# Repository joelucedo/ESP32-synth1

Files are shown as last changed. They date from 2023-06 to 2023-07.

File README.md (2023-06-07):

## ESP32 SYNTH
***ESP32 Wrover E/IE based synthesizer***

ESP32 synth

## STATUS
Work in progress.
</br>
## SPECS
Audio in/out and headphone,  MIDI in/out/thru, 16 pot + 1 volume pot, USB-C, reset switch

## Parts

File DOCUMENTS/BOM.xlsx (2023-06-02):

ESP32 SYNTH 1 - BOM
Ref | Description | Package/Mounting | Value | Quantity | Manufacturer | Manufacturer PN | Supplier | Supplier PN | Cost/Unit | Stock | Basic/Extended | Notes
RESISTORS
 | SMD Thick Film Resistors 125mW ±1% | 0805 | 33R |  | UNI-ROYAL | 0805W8F330JT5E | JLCPCB | C17634 |  |  | Basic
 | SMD Thick Film Resistors 125mW ±1% | 0805 | 100R |  | UNI-ROYAL | 0805W8F1000T5E | JLCPCB | C17408 |  |  | Basic
 | SMD Thick Film Resistors 100mW ±1% | 0603 | 220R |  | UNI-ROYAL | 0603WAF2200T5E | JLCPCB | C22962 |  |  | Basic
 | SMD Thick Film Resistors 100mW ±1% | 0603 | 1k |  | UNI-ROYAL | 0603WAF1001T5E | JLCPCB | C21190 |  |  | Basic
 | SMD Thick Film Resistors 100mW ±5% | 0603 | 1,5k |  | UNI-ROYAL | CQ03WAJ0152T5E | JLCPCB | C2759693 |  | 3458 | Extended
 | SMD Thick Film Resistors 100mW ±1% | 0603 | 2.2k |  | UNI-ROYAL | 0603WAF2201T5E | JLCPCB | C4190 |  |  | Basic
 | SMD Thick Film Resistors 100mW ±1% | 0603 | 5,1k |  | UNI-ROYAL | 0603WAF5101T5E | JLCPCB | C23186
 | SMD Thick Film Resistors 100mW ±1% | 0603 | 10k |  | UNI-ROYAL | 0603WAF1002T5E | JLCPCB | C25804 |  |  | Basic
 | SMD Thick Film Resistors 100mW ±1% | 0603 | 22k |  | UNI-ROYAL | 0603WAF2202T5E | JLCPCB | C31850 |  |  | Basic
 | SMD Thick Film Resistors 100mW ±1% | 0603 | 47k |  | UNI-ROYAL | 0603WAF4702T5E | JLCPCB | C25819 |  |  | Basic
 | SMD Thick Film Resistors 100mW ±1% | 0603 | 100k |  | UNI-ROYAL | 0603WAF1003T5E | JLCPCB | C25803
CAPACITORS
 | SMD MLCC 50V X7R ±10% | 0603 | 100nF |  | YAGEO | CC0603KRX7R9BB104 | JLCPCB | C14663 |  |  | Basic
 | SMD MLCC 50V X5R ±10% | 0603 | 1uF |  | Samsung Electro-Mechanics | CL10A105KB8NNNC | JLCPCB | C15849 |  |  | Basic
 | SMD MLCC 16V X5R ±10% | 0603 | 4.7uF |  | Samsung Electro-Mechanics | CL10A475KO8NNNC | JLCPCB | C19666 |  |  | Basic
 | SMD MLCC 25V X5R ±20% | 0603 | 10uF |  | Samsung Electro-Mechanics | CL10A106MA8NRNC | JLCPCB | C96446 |  |  | Basic
 | SMD MLCC 6.3V X5R ±20% | 0603 | 22uF |  | Samsung Electro-Mechanics | CL10A226MQ8NRNC | JLCPCB | C59461 |  |  | Basic
 | SMD Aluminum Electrolytic Capacitors 10V ±20% | SMD,D6.3xL5.4mm | 220uF |  | Honor Elec | RVT1A221M0605 | JLCPCB | C3345 |  | 52121 | Extended
INDUCTORS
 | SMD Inductor 1.8A ±20% 80mΩ | SMD 3.5x3x2.1mm | 2.2uH |  | YJYCOIN | CD32YP0302-2R2M | JLCPCB | C492258 |  | 222 | Extended
FERRITE BEAD
 | Ferrite Bead - 800mA - 80mΩ - ±25% | 0603 | 120R@100MHz |  | MURATA | BLM18AG121SN1D | JLCPCB | C76892 |  | 66550 | Extended
 | Ferrite bead - 1.3A - 150mΩ - ±25% | 0603 | 600R@100MHz |  | SUNLORD | UPZ1608U601-1R3TF | JLCPCB | C97000 |  | 91257 | Extended
INTEGRATED CIRCUITS
 | ESP32 Wrover E ou IE | SMD |  |  | ESPRESSIF
 | USB UART converter | QFN-28-EP(5x5) |  |  | SILICON LABS | CP2102N-A02-GQFN28R | JLCPCB | C964632 | $2.0723 | 1907 | Extended
 | Audio codec | WQFN-32-EP(5x5) |  |  | CIRRUS LOGIC | WM8978CGEFL/RV | JLCPCB | C323850 | $5.1651 | 1085 | Extended
 | Hex inverter - Schmitt Trigger | SOIC-14 |  |  | NEXPERIA | 74HC04D,653 | JLCPCB | C5590 |  |  | Basic
 | Optocoupler | SMD-8P |  |  | EVERLIGHT | 6N137S1(TA) | JLCPCB | C110020 |  |  | Basic
 | Multiplexer | SOIC-24-300mil |  |  | TEXAS INSTRUMENTS | CD74HC4067 | JLCPCB | C496123 |  | 1953 | Extended
POWER
 | Step down switching regulator | SOT-23-5 |  |  | TEXAS INSTRUMENTS | TLV62569DBVR | JLCPCB | C141836 |  | 29173 | Extended
 | 200mA - 70dB@(100Hz), 43dB@(100kHz) 180mV@(200mA) Fixed 3.3V | SOT-23-5 |  |  | TEXAS INSTRUMENTS | TPS79333DBVR | JLCPCB | C9840 |  | 2029 | Extended
 | Switching diode - 75V - 400mW - Single 1.25V@150mA | SOD-123 |  |  | SEMTECH | 1N4148W | JLCPCB | C81598 |  |  | Basic
 | Resettable fuse - 9V - 200mA - 100A - 500mA | 805 |  |  | RUILON | SMD0805P020TF | JLCPCB | C20976 |  | 11226 | Extended
 | ESD Protection | SOT-143 |  |  | MSKSEMI | SP0503BAHTG | JLCPCB | C3029025 |  | 8172 | Extended
 | NPN Transistor | SOT-23 |  |  | JSCJ | MMBT3904 | JLCPCB | C20526 |  |  | Basic
MECHANICALS
 | Deck MicroSD card (TF card) Self bomb SMD SD Card Connectors | SMD |  |  | SOFNG | TF-15x15 | JLCPCB | C111196 |  | 7675 | Extended
 | SPST - NO - 50mA -100mΩ - 160gf - 12V | SMD 5.1mm 1.5mm |  |  | XKB CONNECTIVITY | TS-1187A-B-A-B | JLCPCB | C318884 |  |  | Basic
 | SMD USB-C Connector 5A 16 Female | SMD |  |  | YIYUAN | YTC-TC16S-28 | JLCPCB | C2927293 |  | 9140 | Extended
 | SMD Pin Header 2x5 1.27mm pitch | SMD |  |  | XFCN | PZ127VS-12-10-H10-A38 | JLCPCB | C2935458 |  | 5190 | Extended
 | 3.5mm headphone jack 235℃ 30V 0.5A | SMD |  |  | XKB Connectivity | PJ-342B-TX-SMT | JLCPCB | C388632 |  | 3562 | Extended
 | Pot, vertical, Linear, 1B tapper, 20%, D Flatted, 25 mm (L), 6mm (⌀), 1 gang, 1 turn, no detent, | Through-hole | 10k |  | Alps Alpine | RK09D1130C2P | Mouser | 688-RK09D1130C2P | 2.05 € | 4962
 | Encoder, 24 PPR, 25 mm (L), 6mm (⌀), with switch, no detent, -30°C +70°C, Snap In | Through-hole |  |  | Bourns | PEC12R-4025F-S24 | Mouser | 652-PEC12R-4025F-S24 | 1.55 € | 1312

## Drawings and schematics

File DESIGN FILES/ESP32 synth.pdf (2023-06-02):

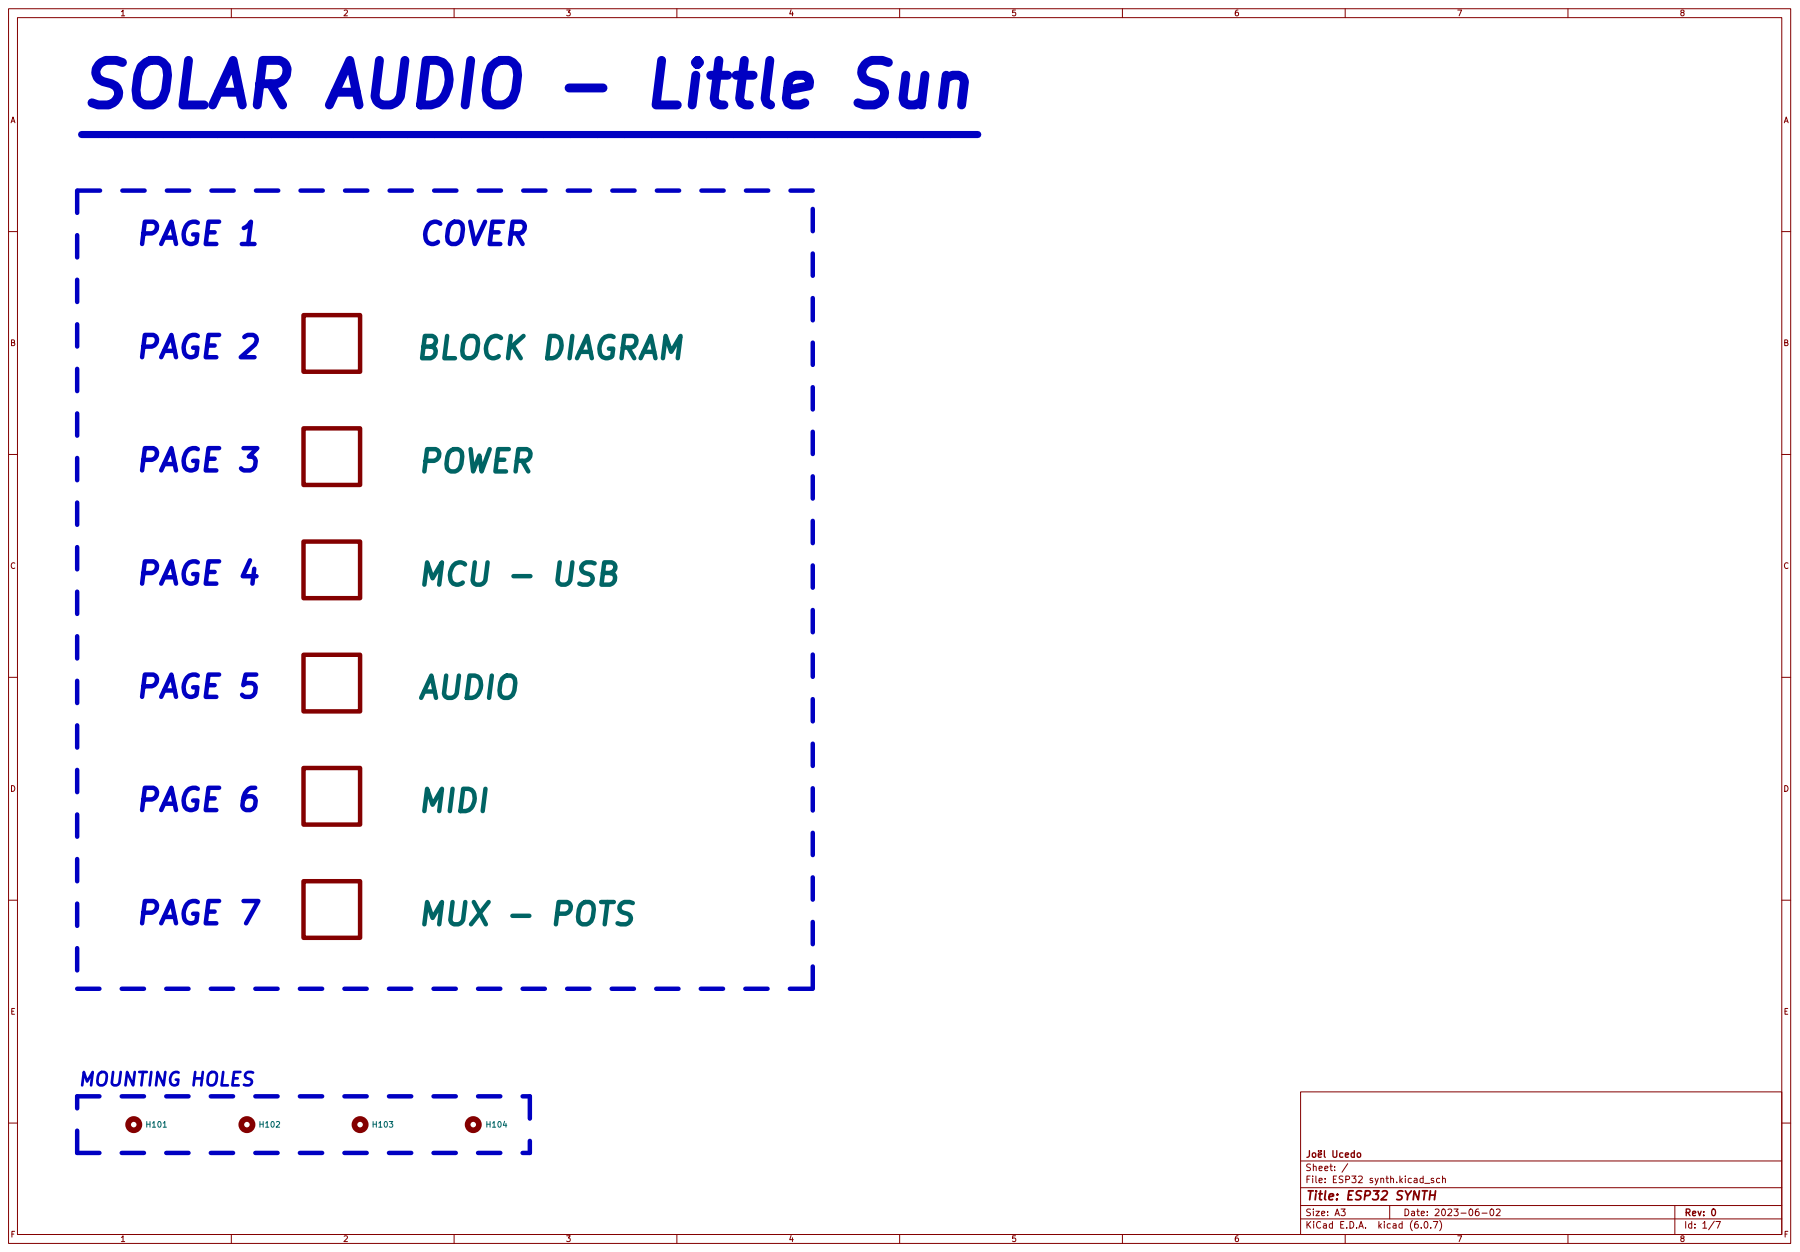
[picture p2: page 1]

SOLAR AUDIO - Little Sun _________________________________

File: ESP32 synth.kicad_sch Sheet: / þÿJoël Ucedo

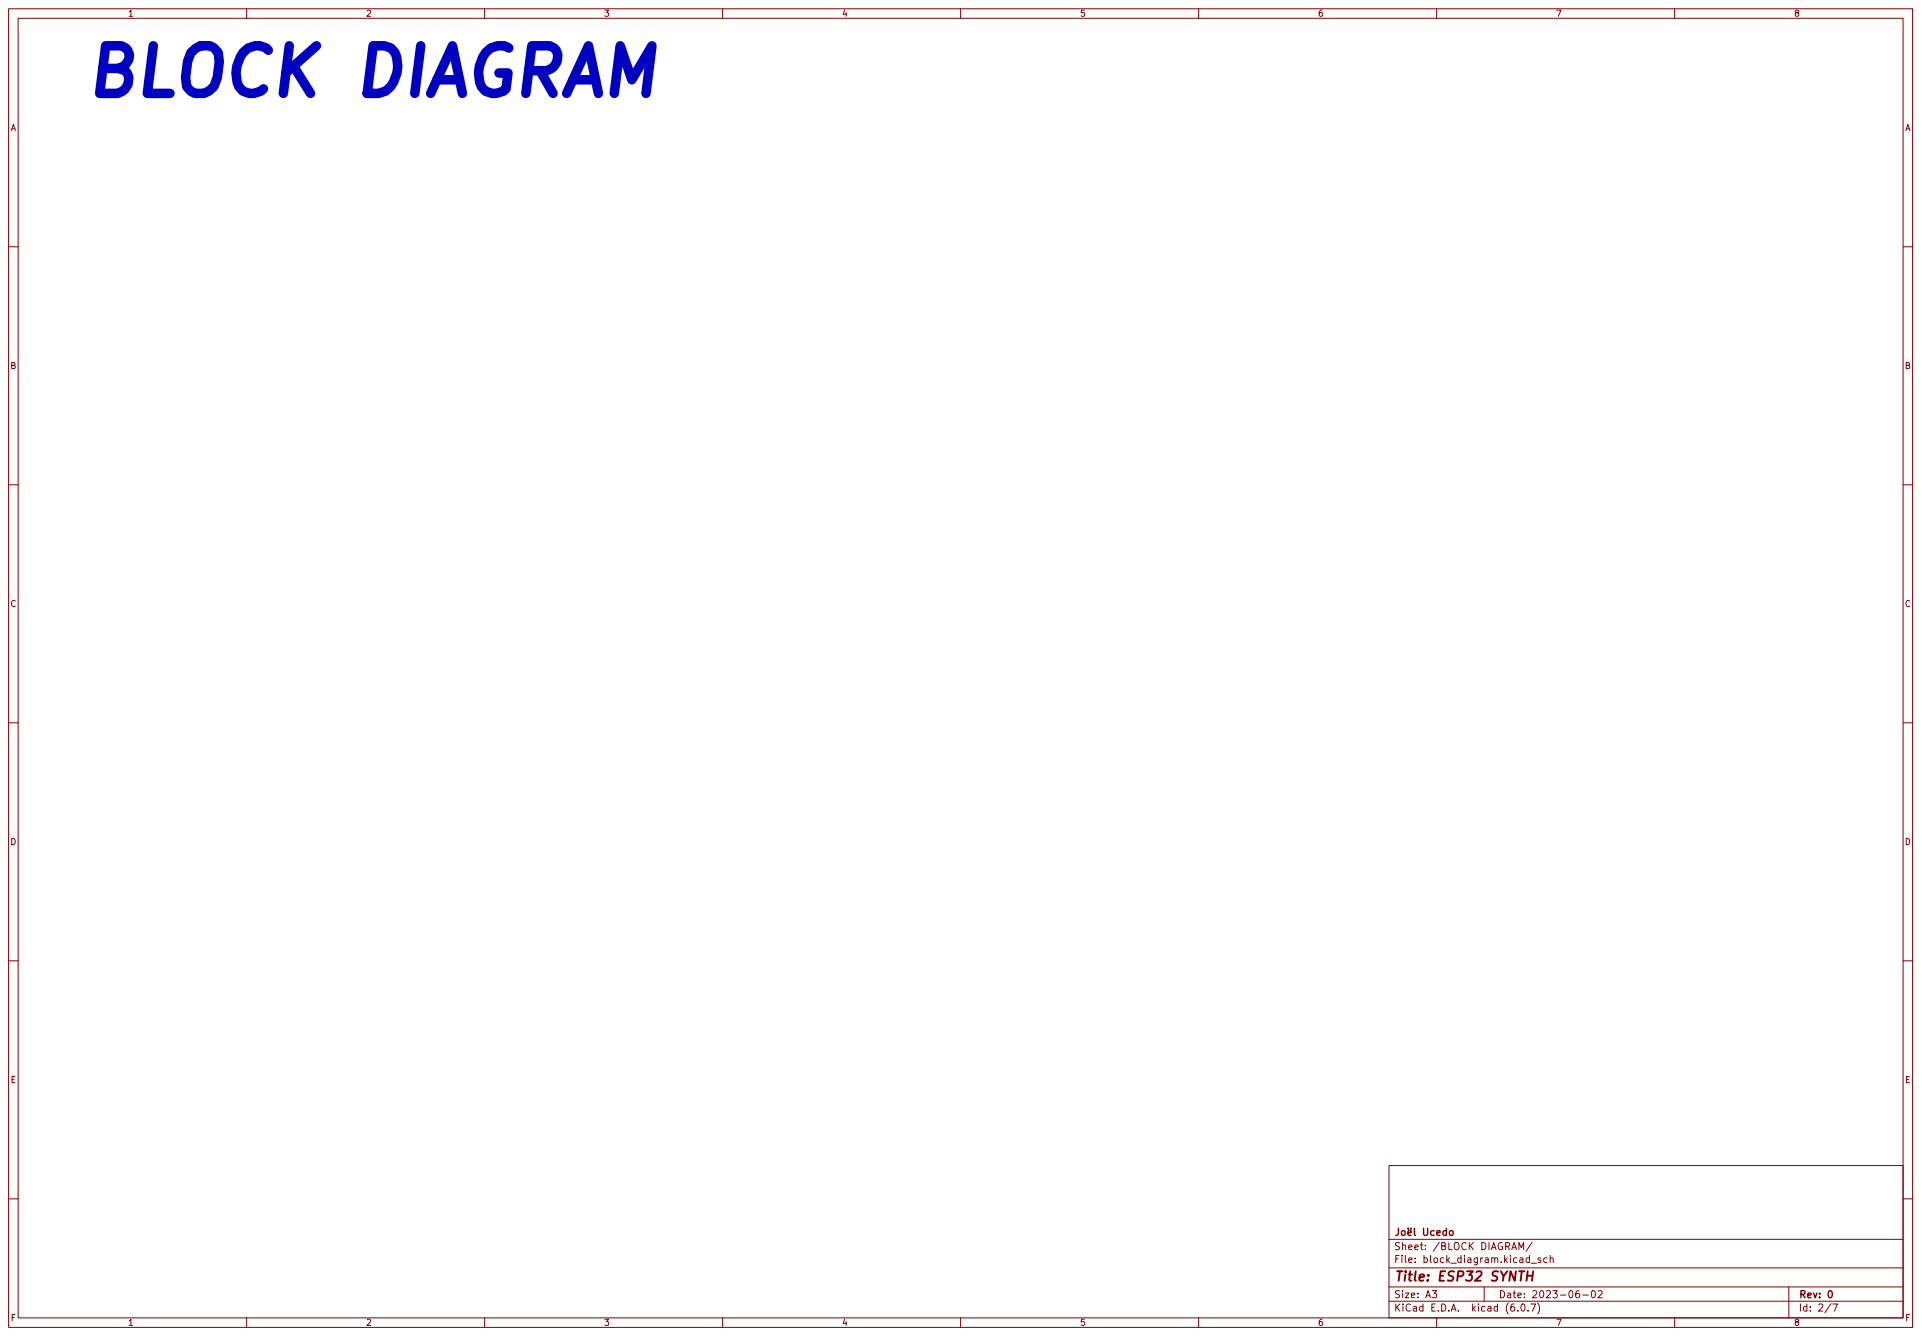
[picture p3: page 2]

File: block_diagram.kicad_sch Sheet: /BLOCK DIAGRAM/ þÿJoël Ucedo

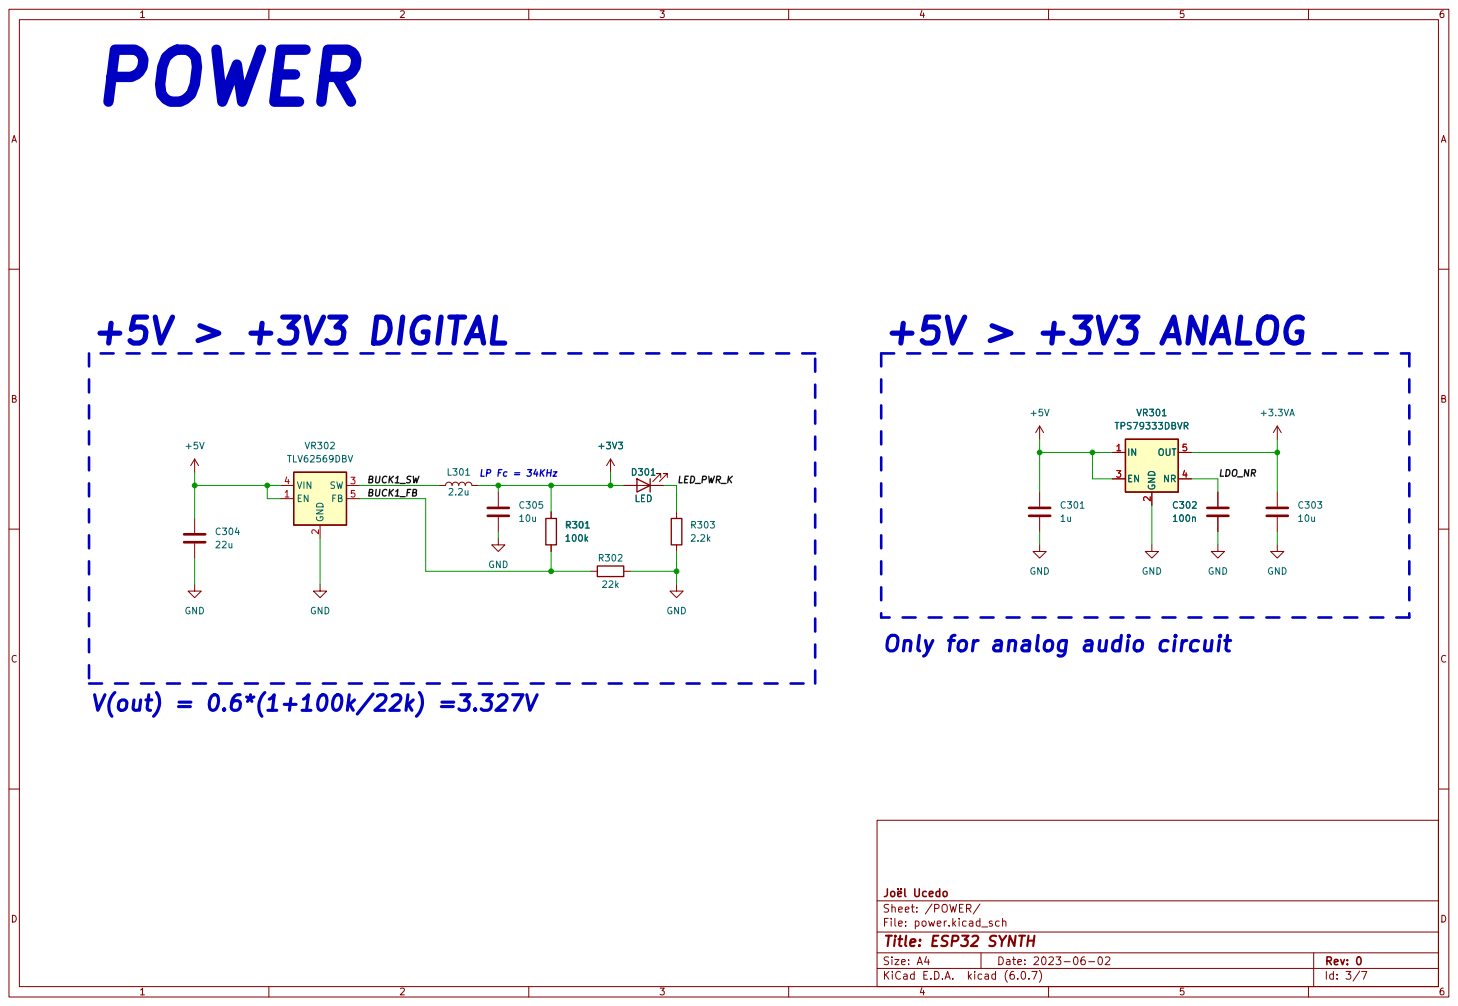
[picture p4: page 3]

2 SW 3 VIN 4 FB 5 VR302 TLV62569DBV GND GND

File: power.kicad_sch Sheet: /POWER/ þÿJoël Ucedo GND

Only for analog audio circuit

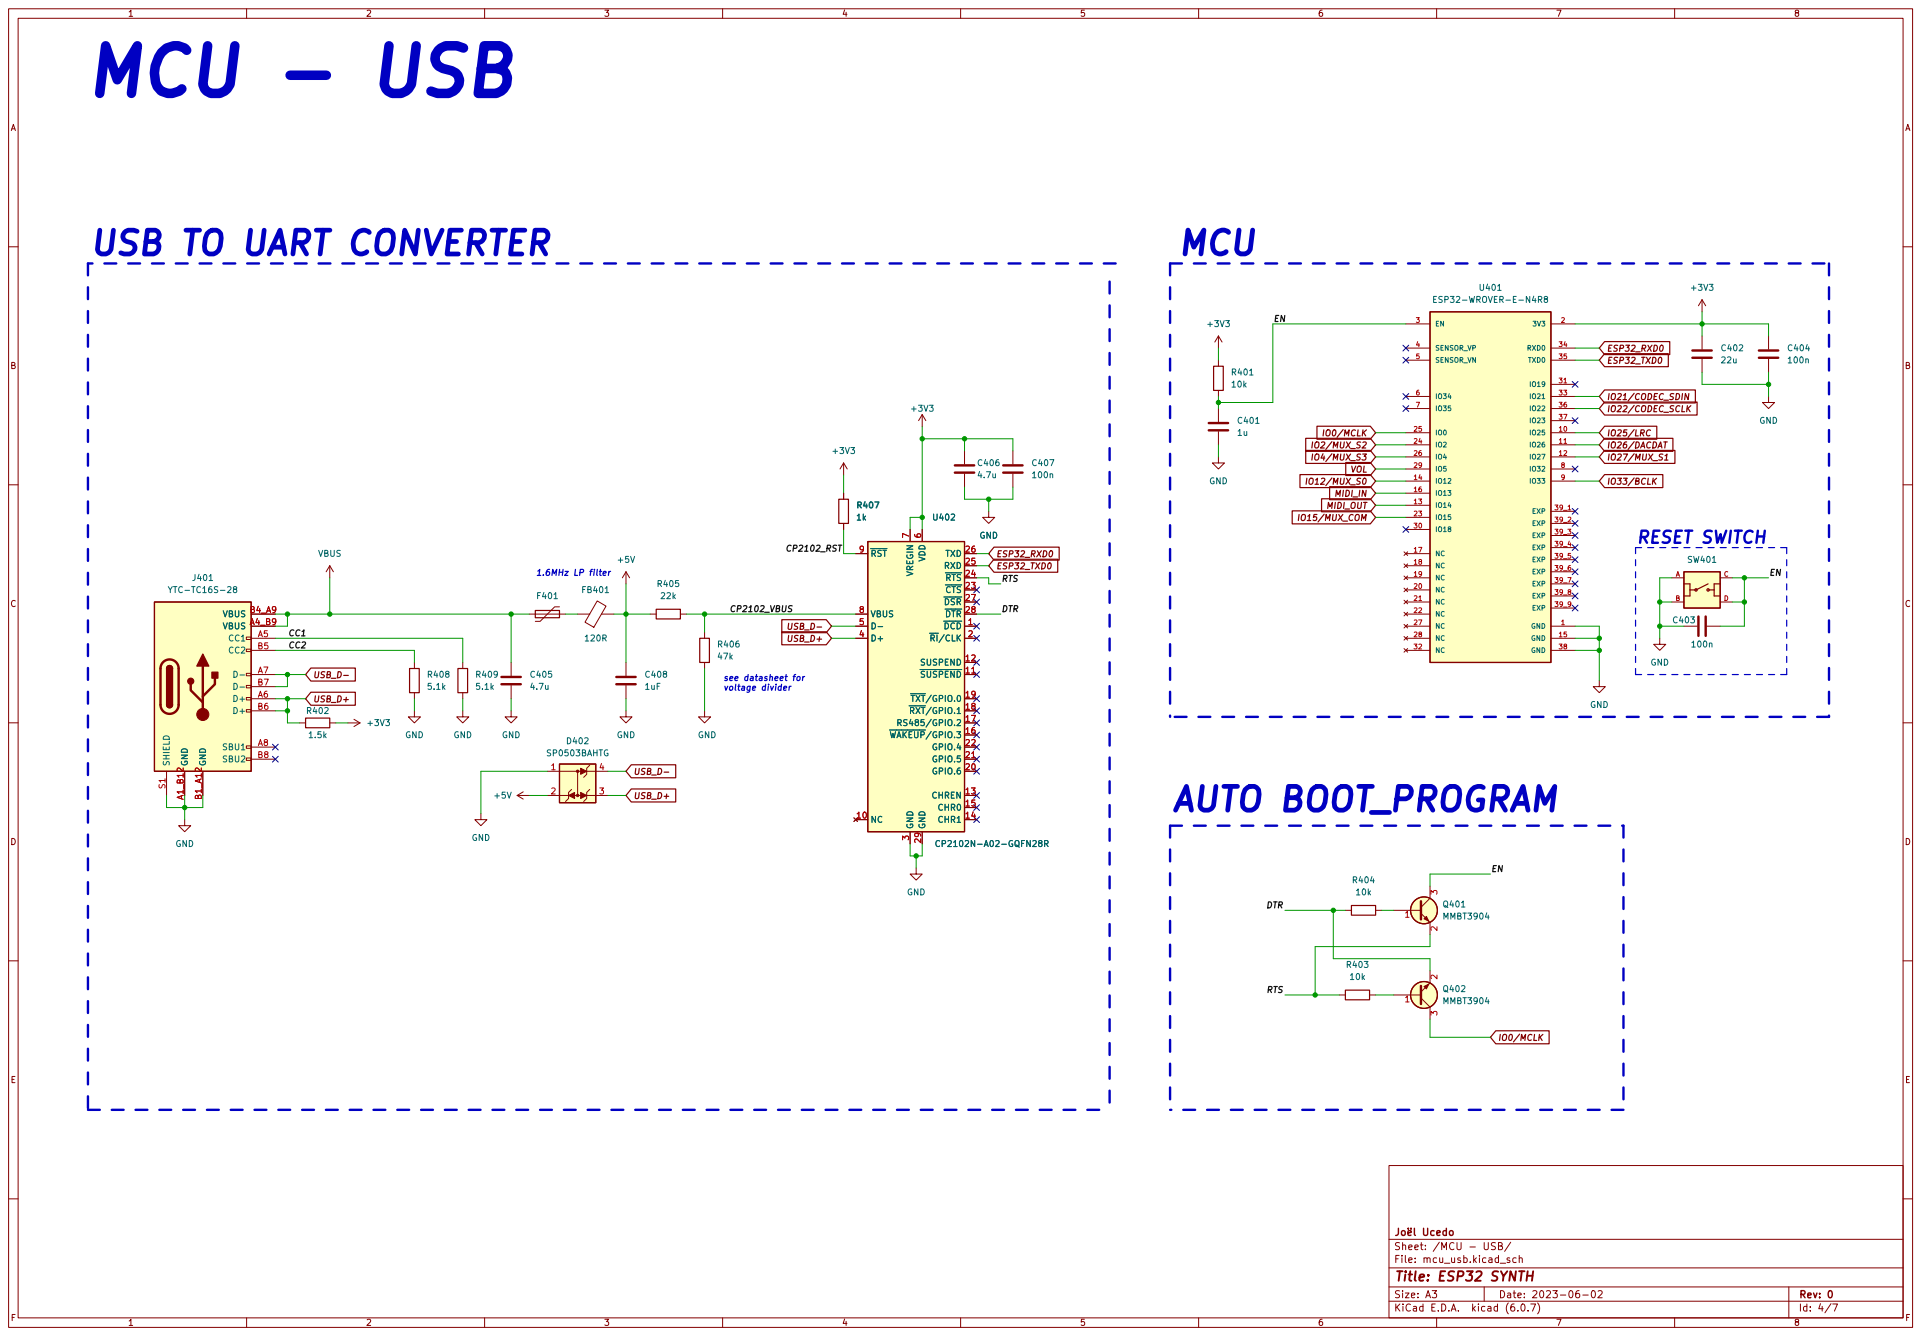
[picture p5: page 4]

see datasheet for voltage divider

File: mcu_usb.kicad_sch Sheet: /MCU - USB/ þÿJoël Ucedo

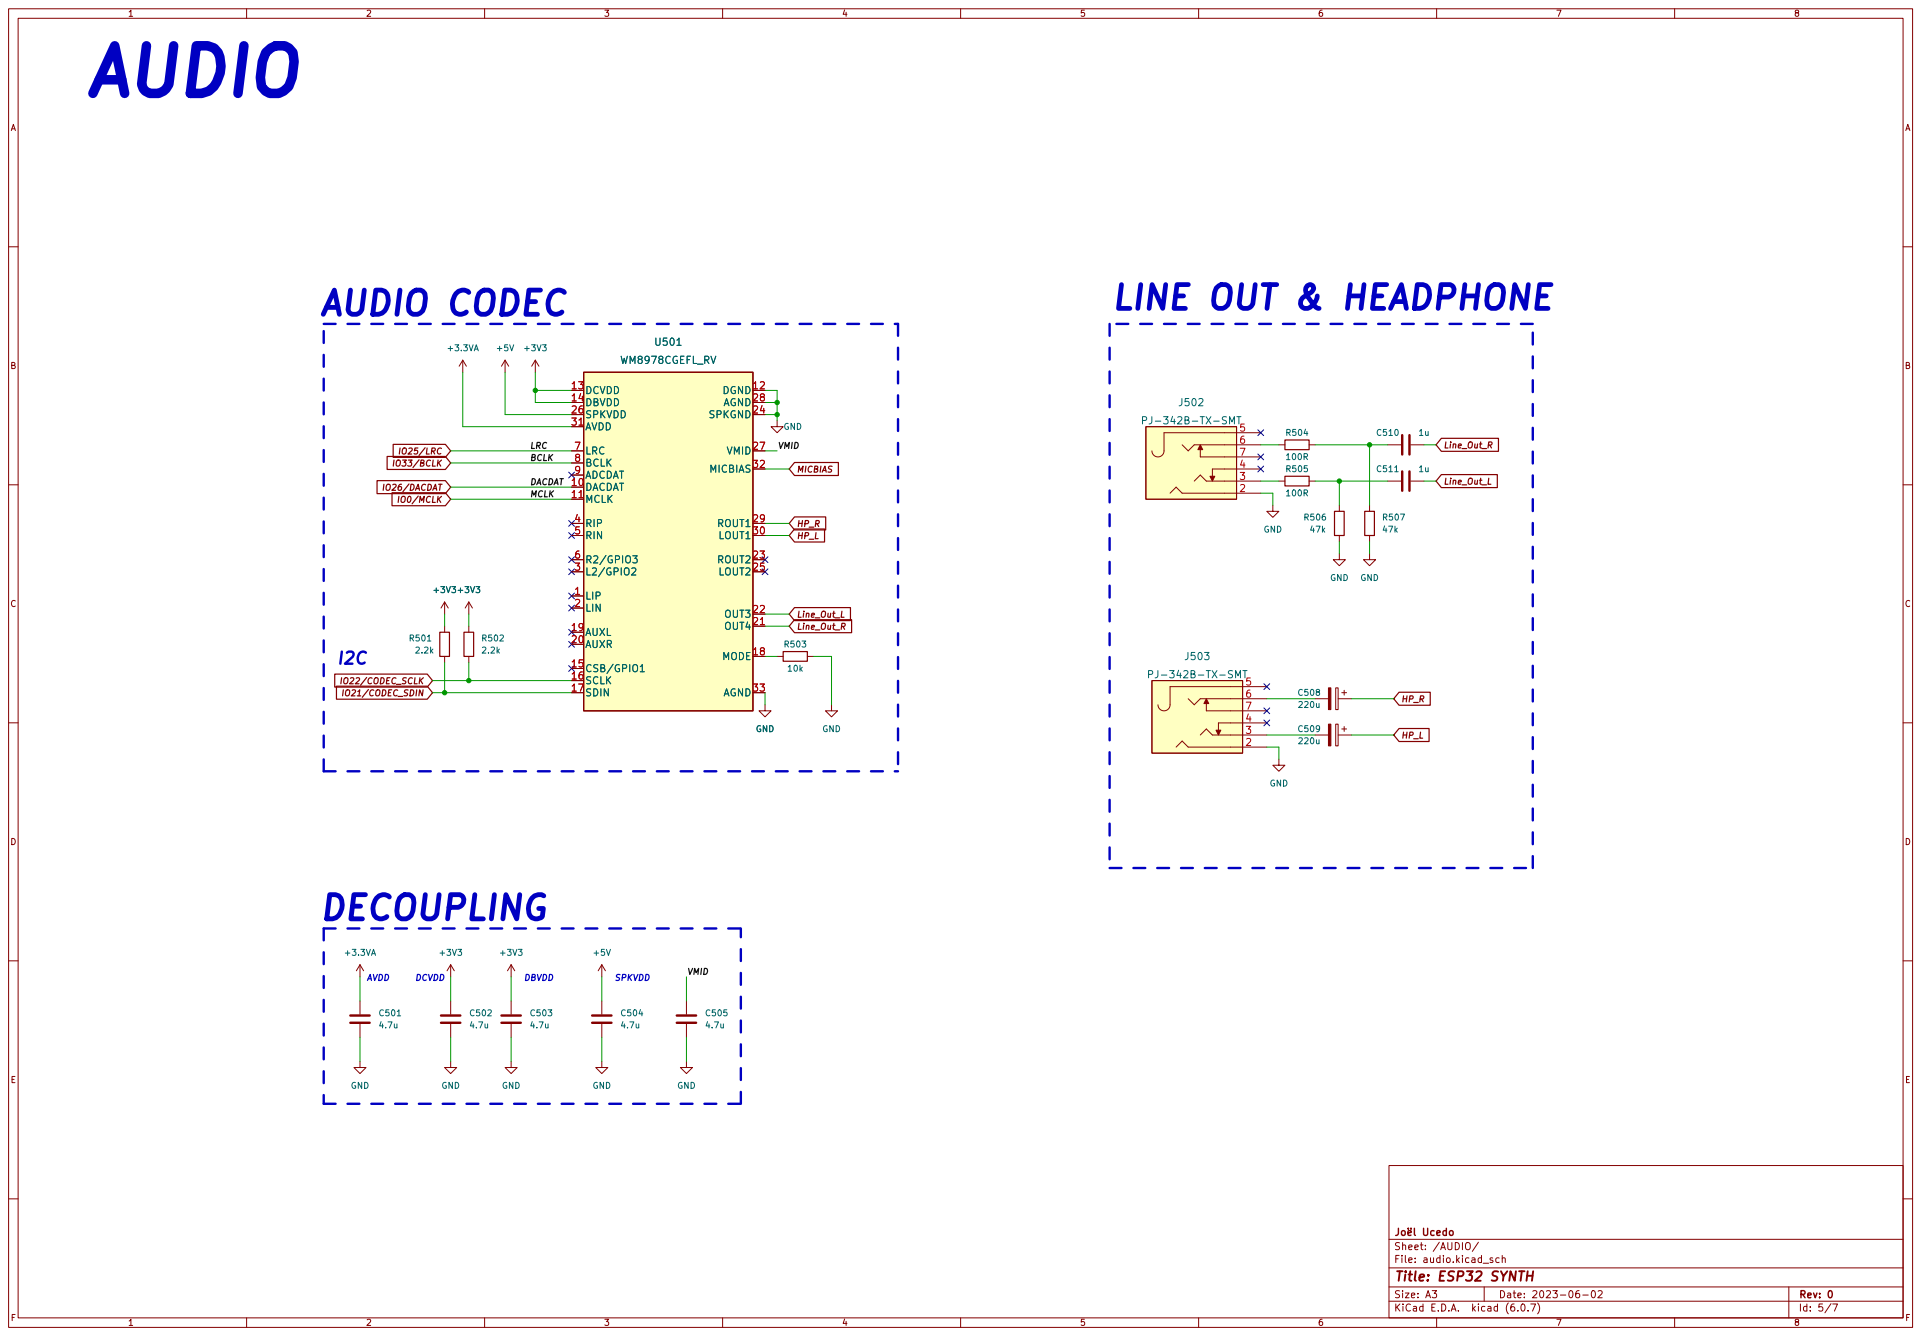
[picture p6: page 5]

File: audio.kicad_sch Sheet: /AUDIO/ þÿJoël Ucedo

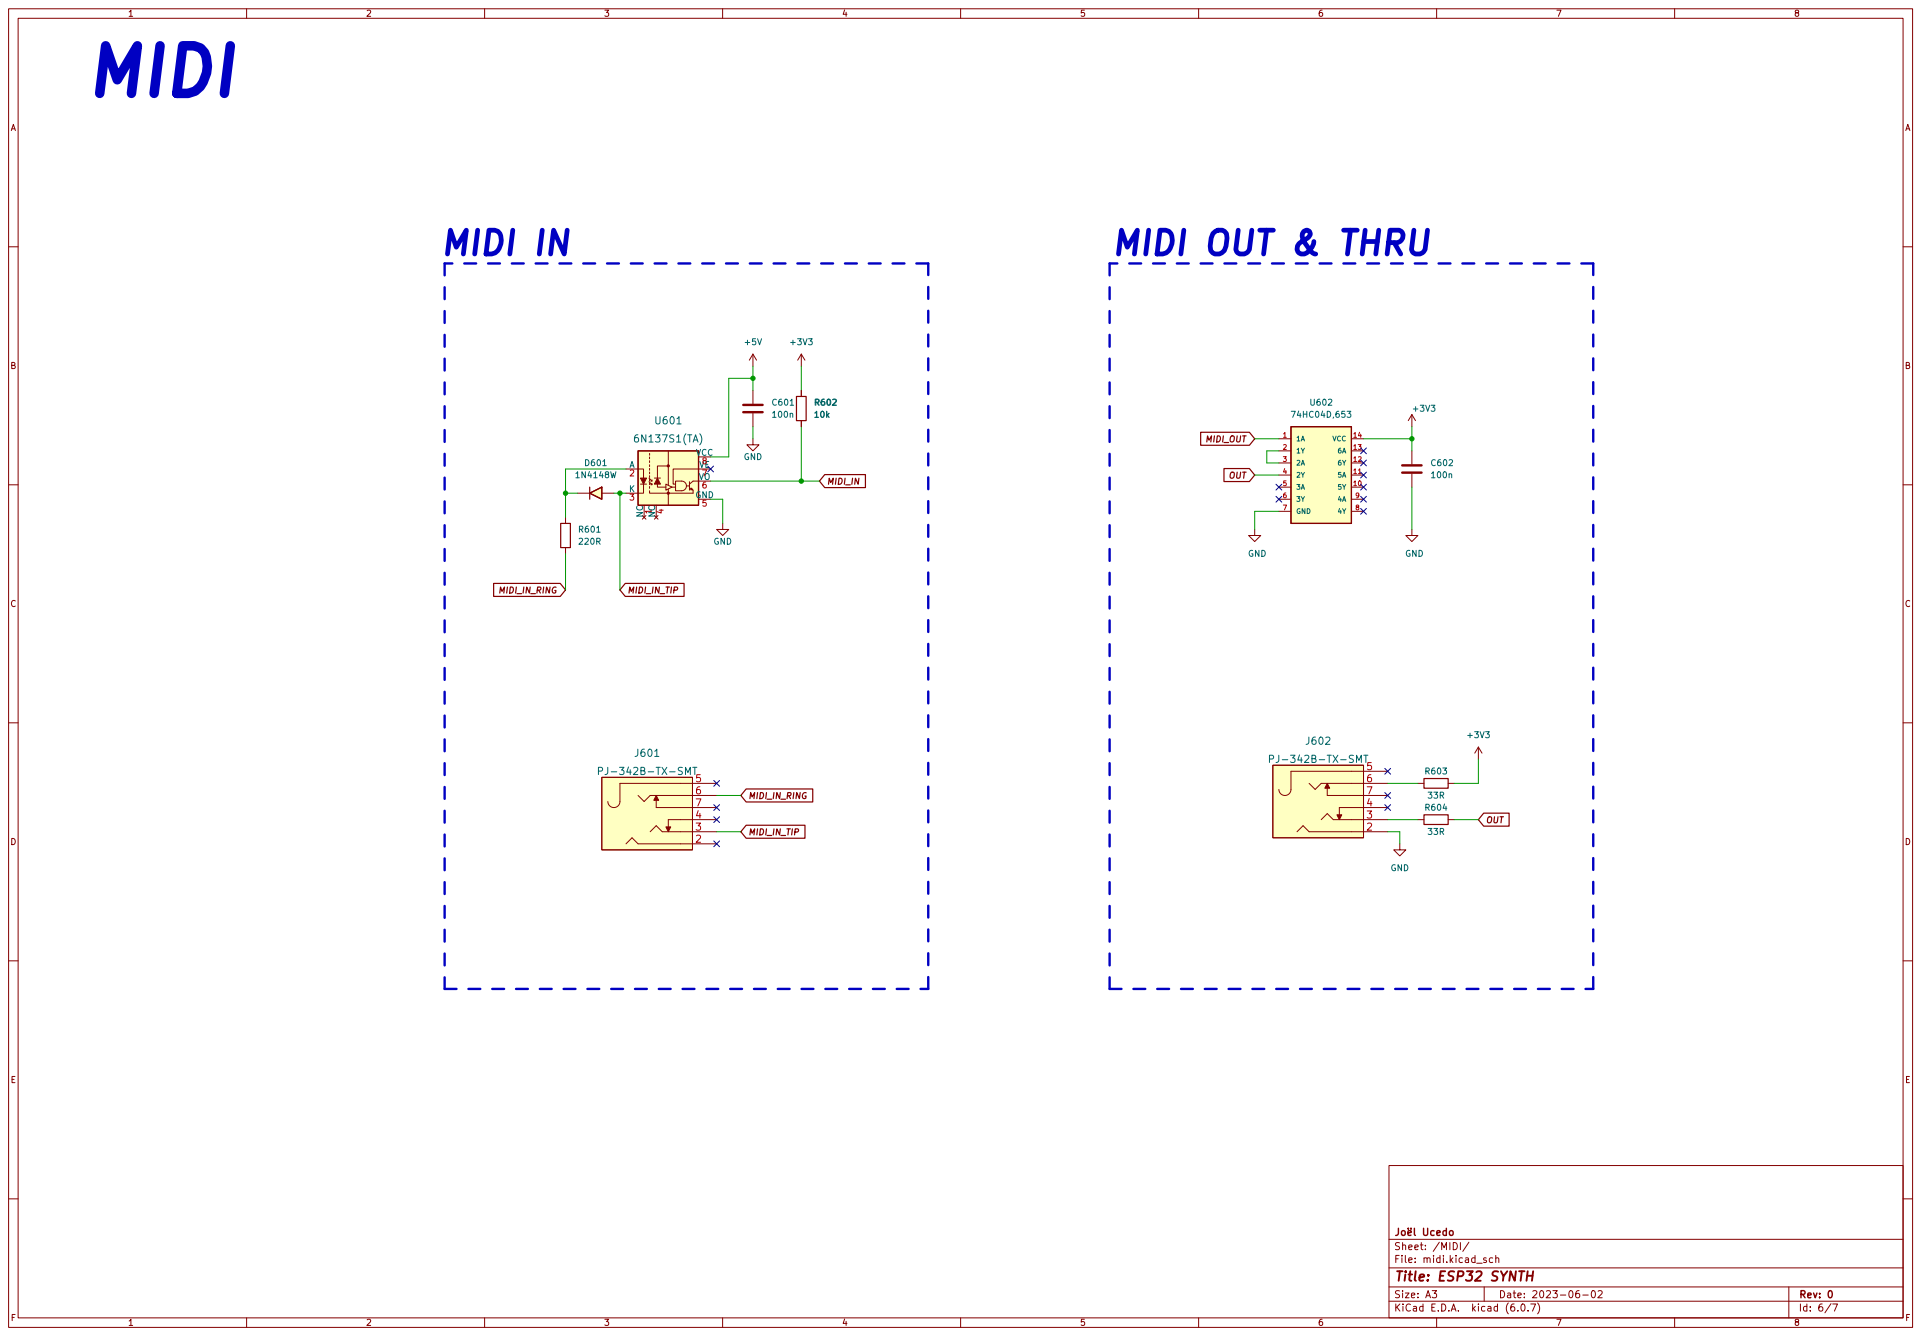
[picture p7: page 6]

File: midi.kicad_sch Sheet: /MIDI/ þÿJoël Ucedo

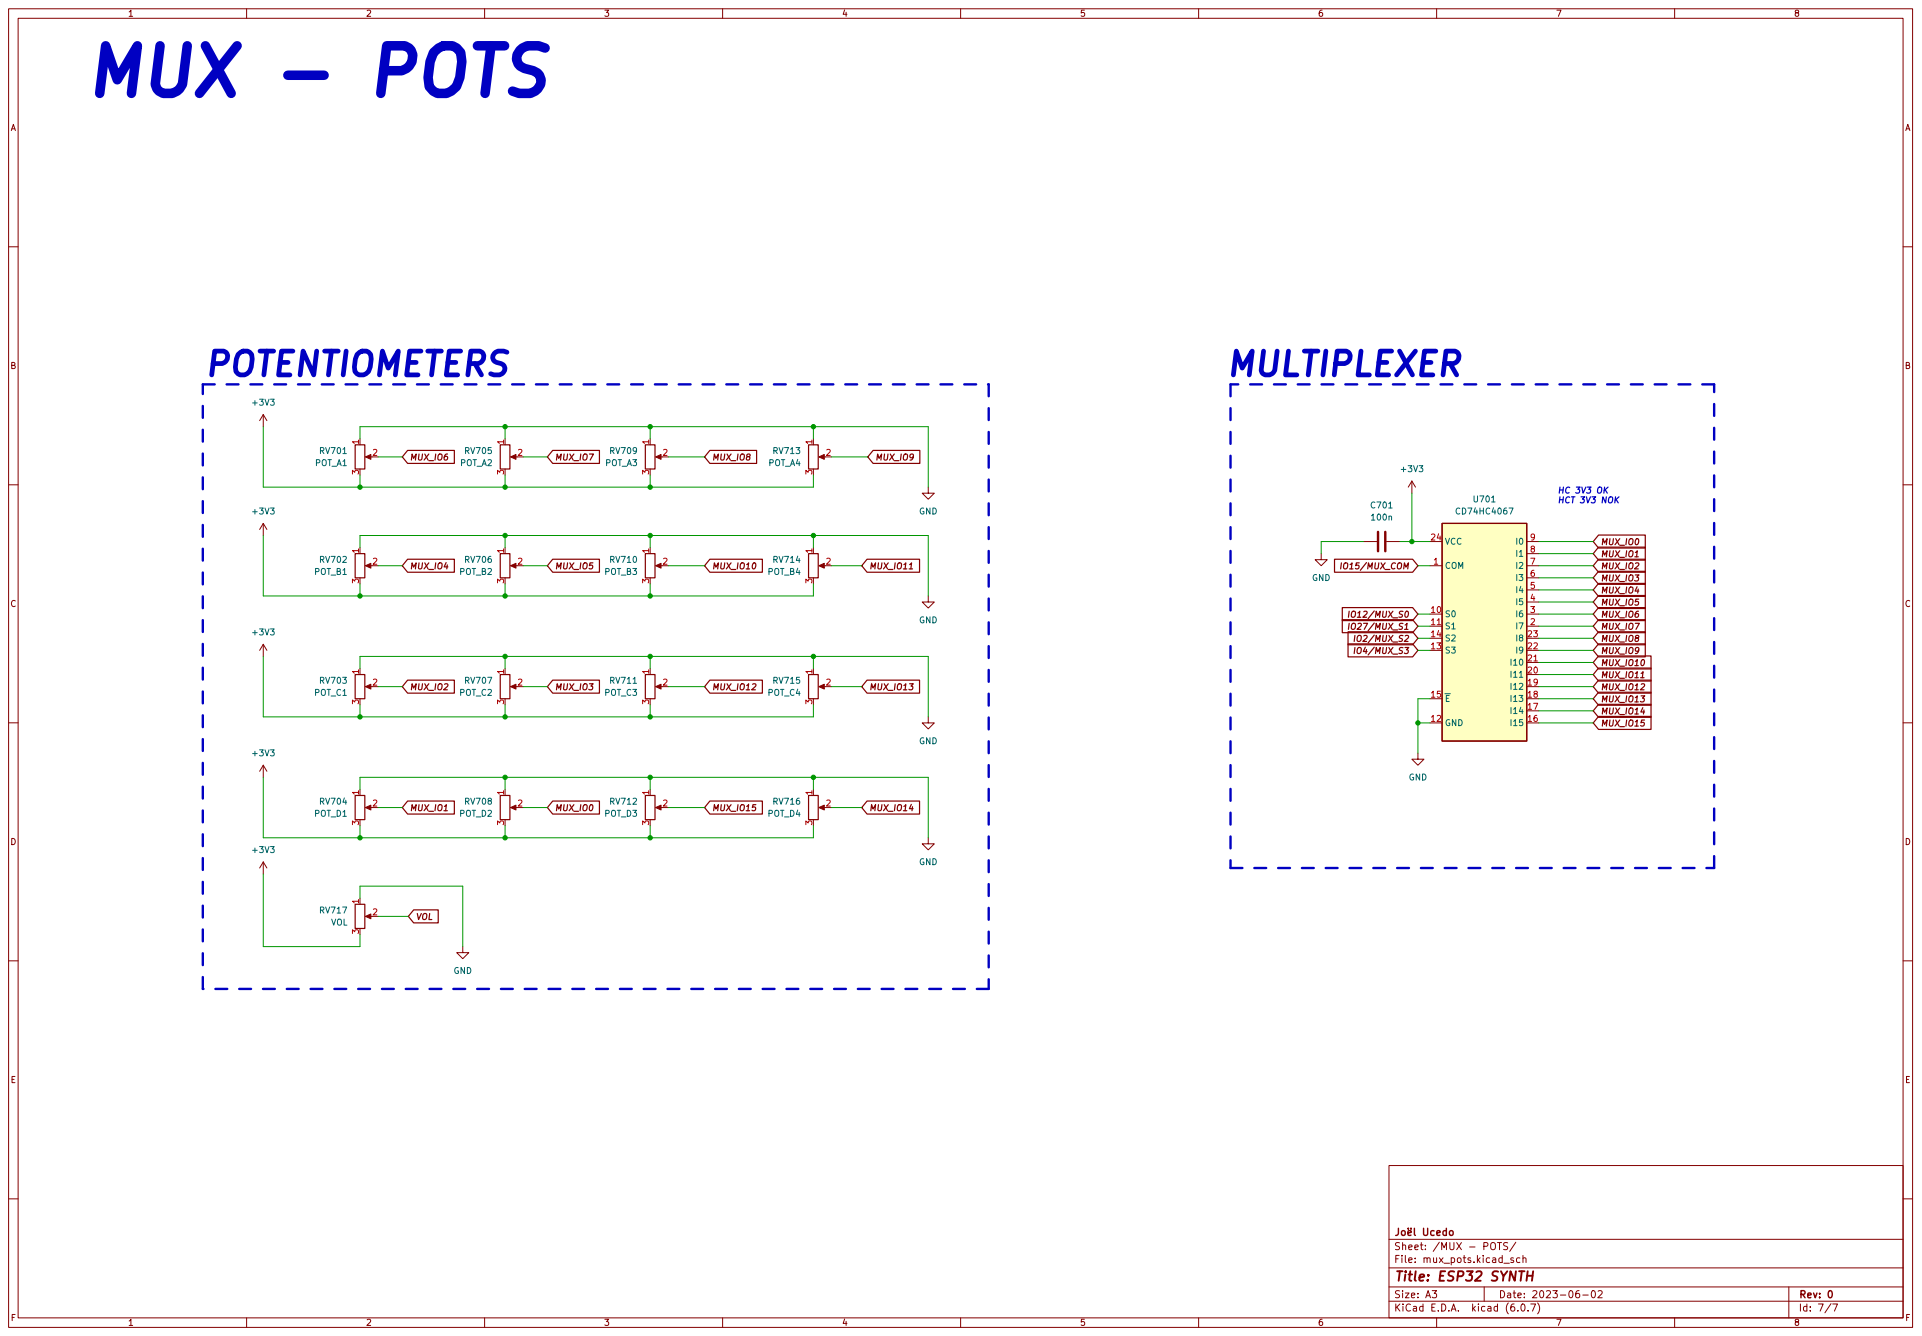
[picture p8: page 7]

HC 3V3 OK HCT 3V3 NOK

File: mux_pots.kicad_sch Sheet: /MUX - POTS/ þÿJoël Ucedo

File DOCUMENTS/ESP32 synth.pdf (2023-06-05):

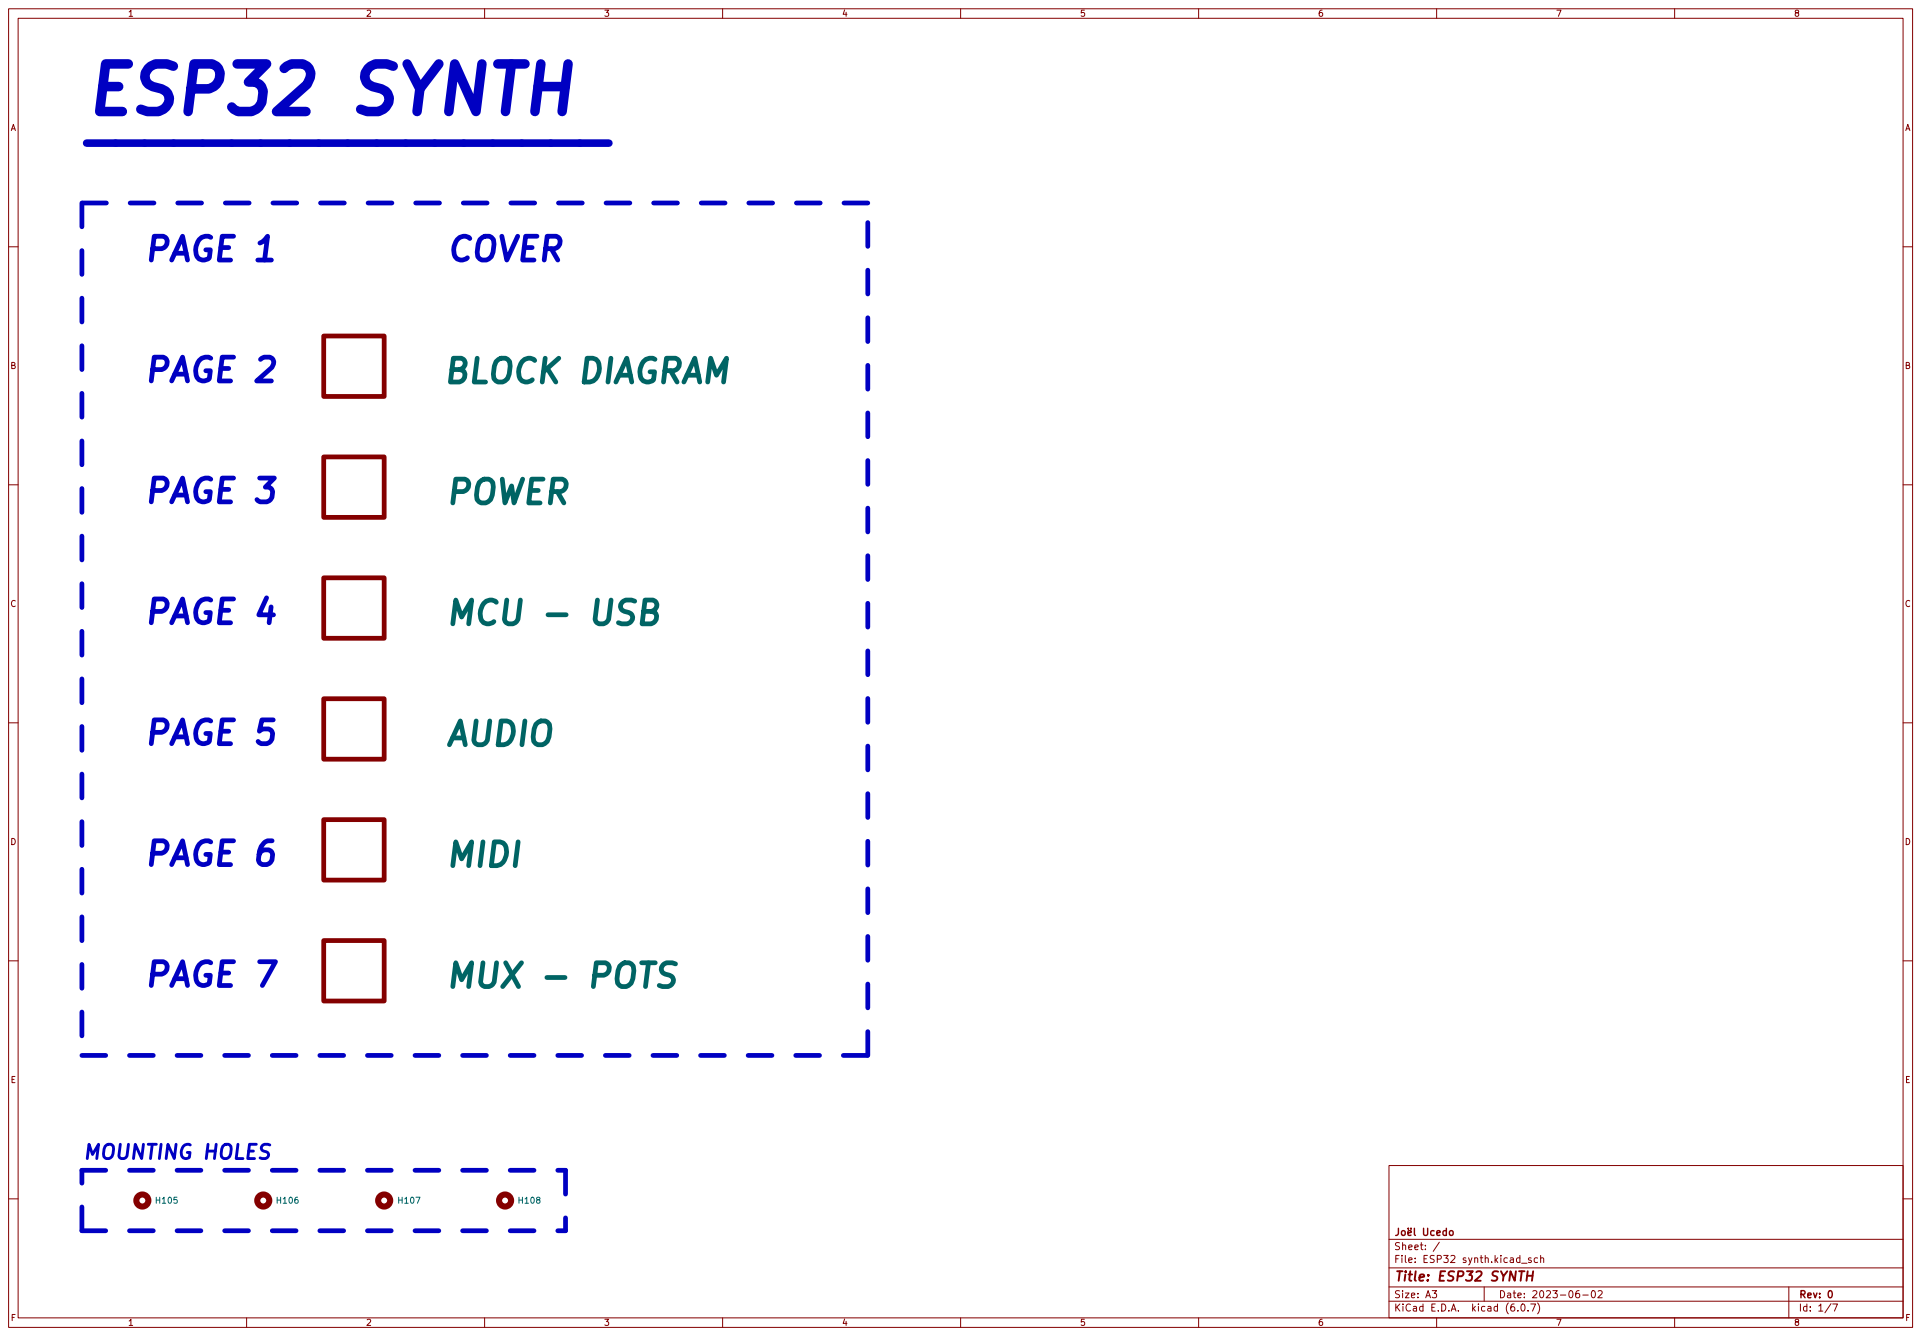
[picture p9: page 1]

File: ESP32 synth.kicad_sch Sheet: / þÿJoël Ucedo


File: block_diagram.kicad_sch Sheet: /BLOCK DIAGRAM/ þÿJoël Ucedo

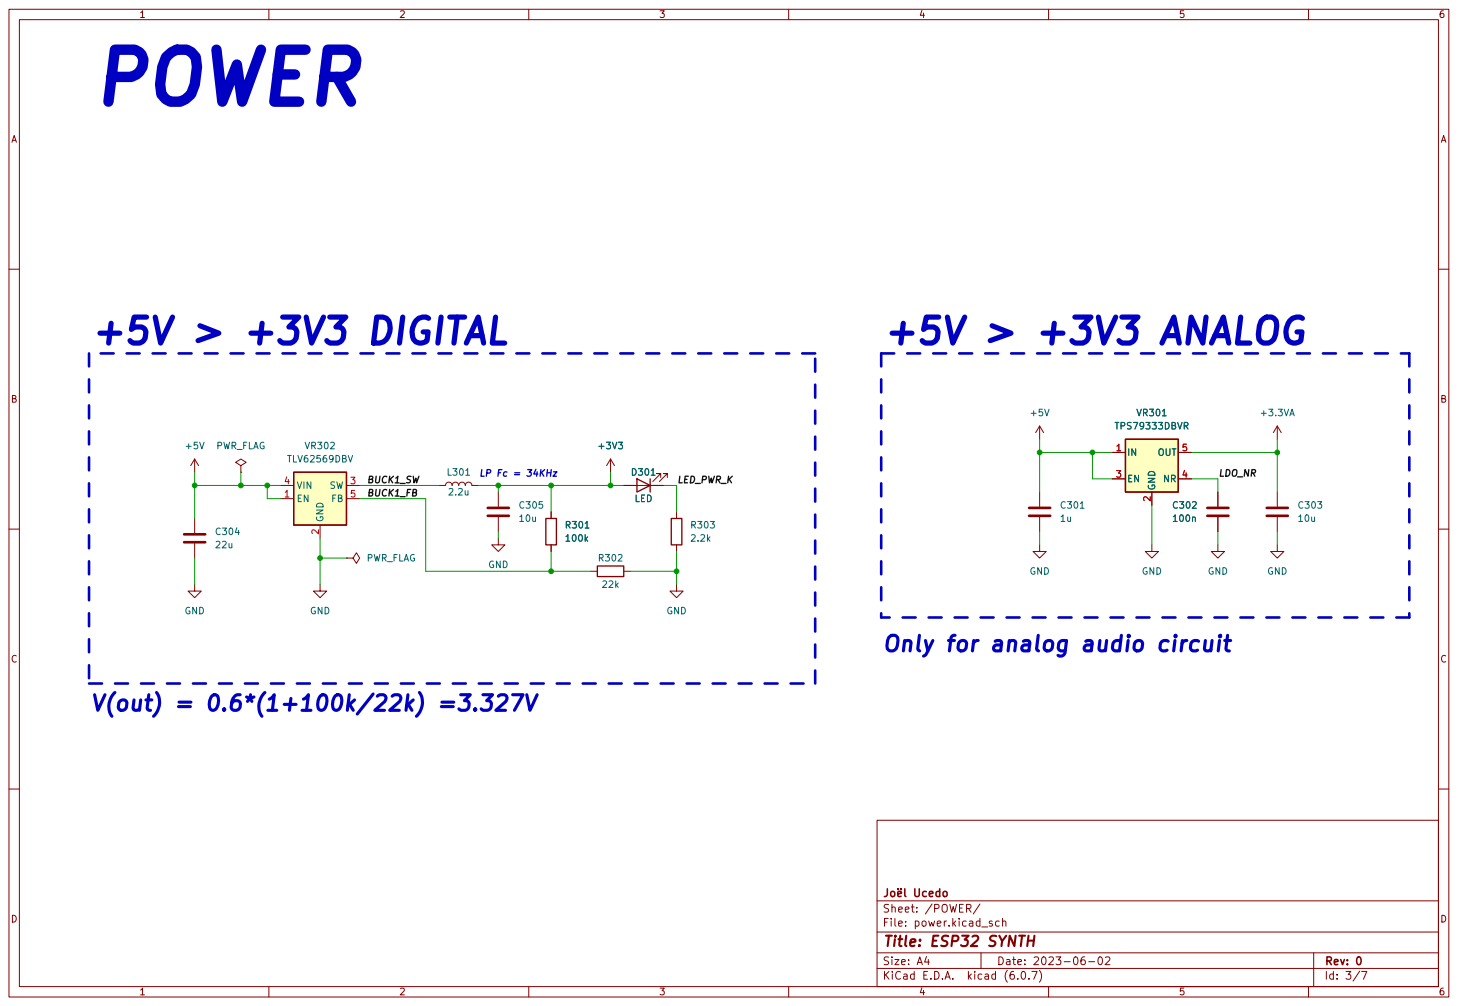
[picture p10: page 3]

Only for analog audio circuit

File: power.kicad_sch Sheet: /POWER/ þÿJoël Ucedo

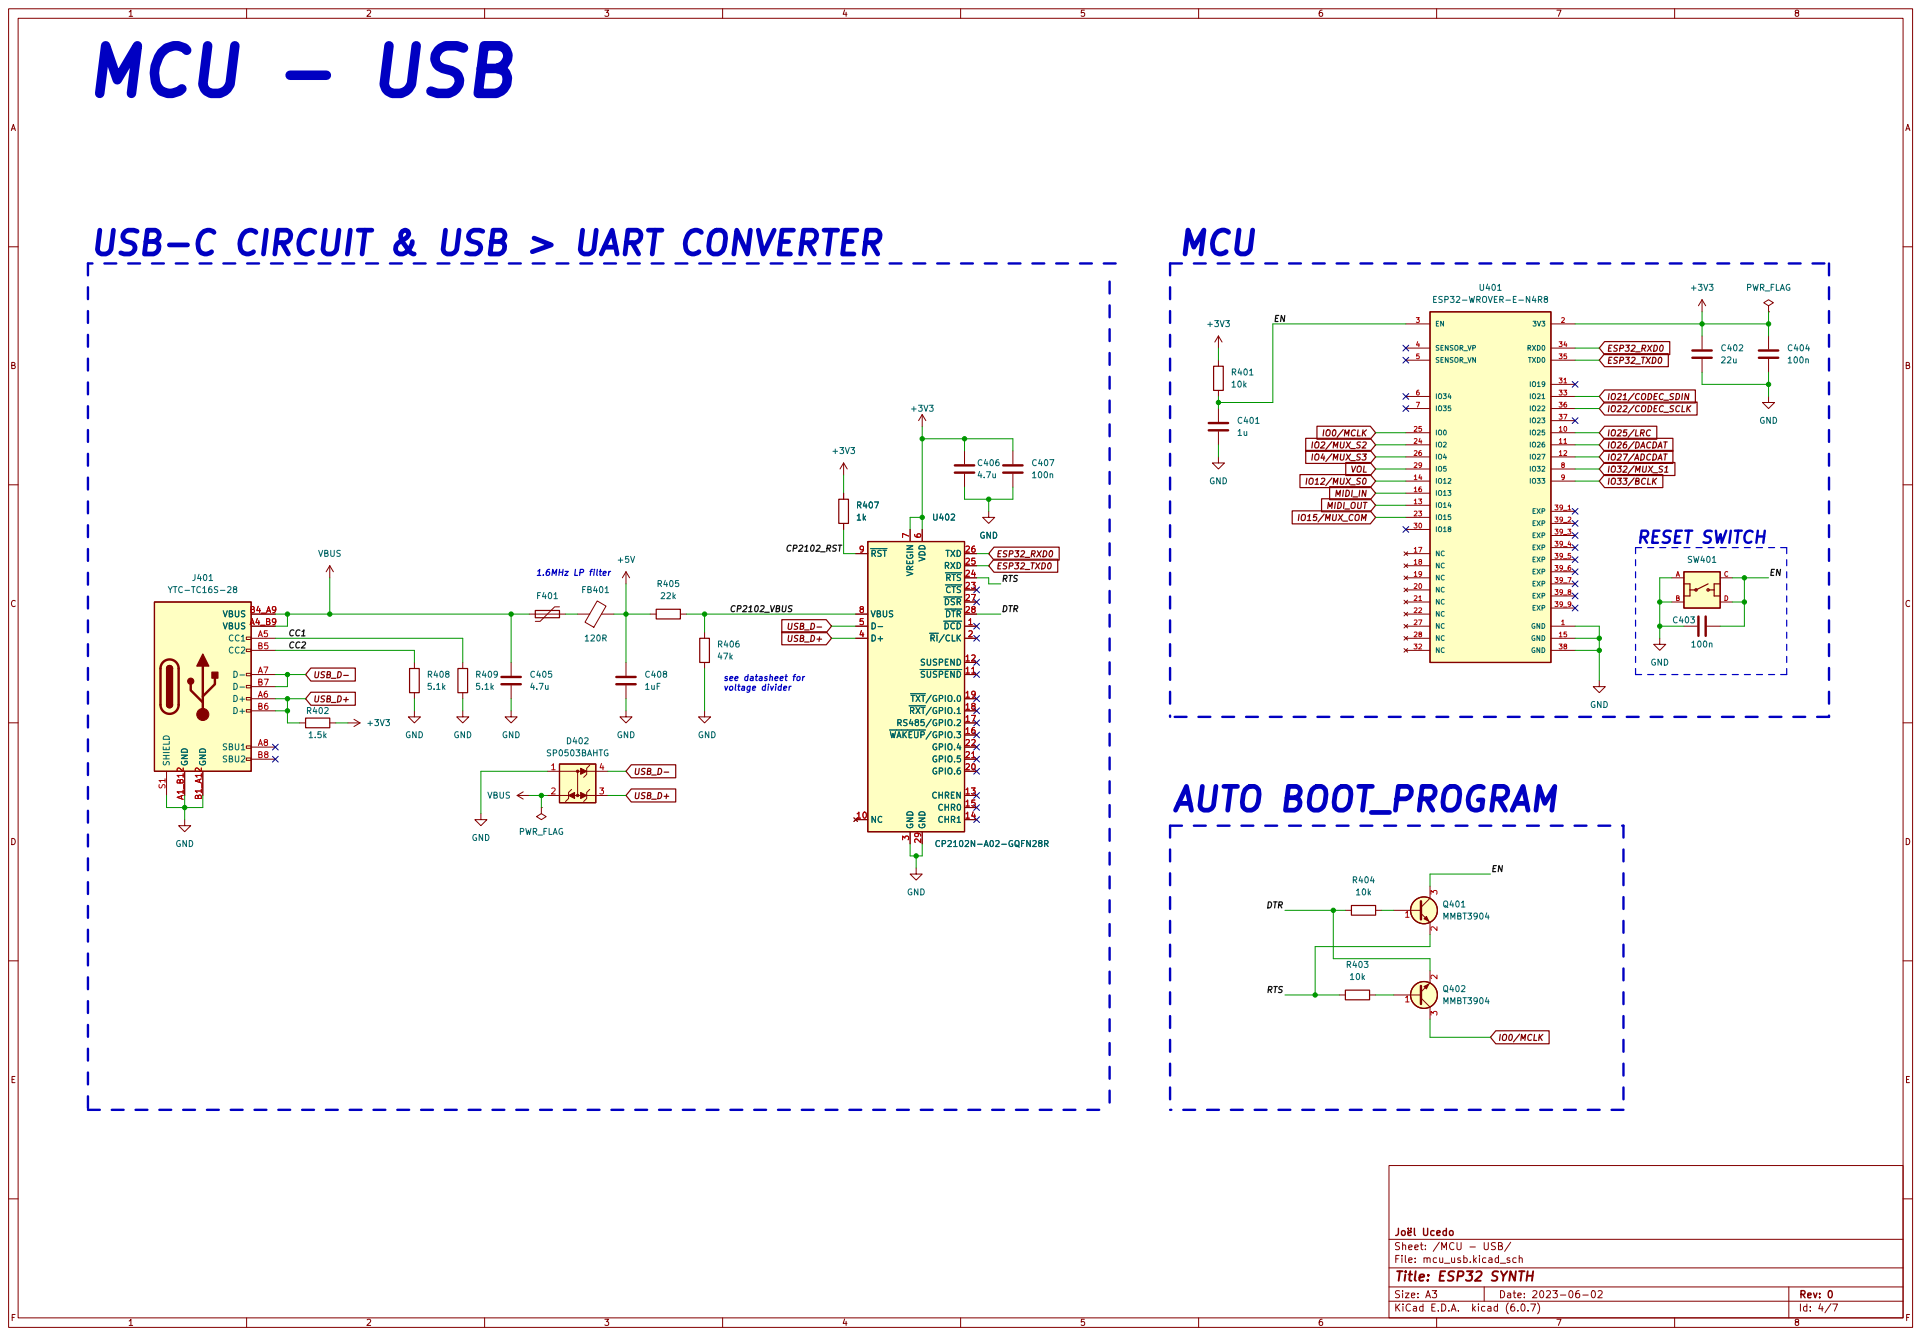
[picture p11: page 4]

File: mcu_usb.kicad_sch Sheet: /MCU - USB/ þÿJoël Ucedo

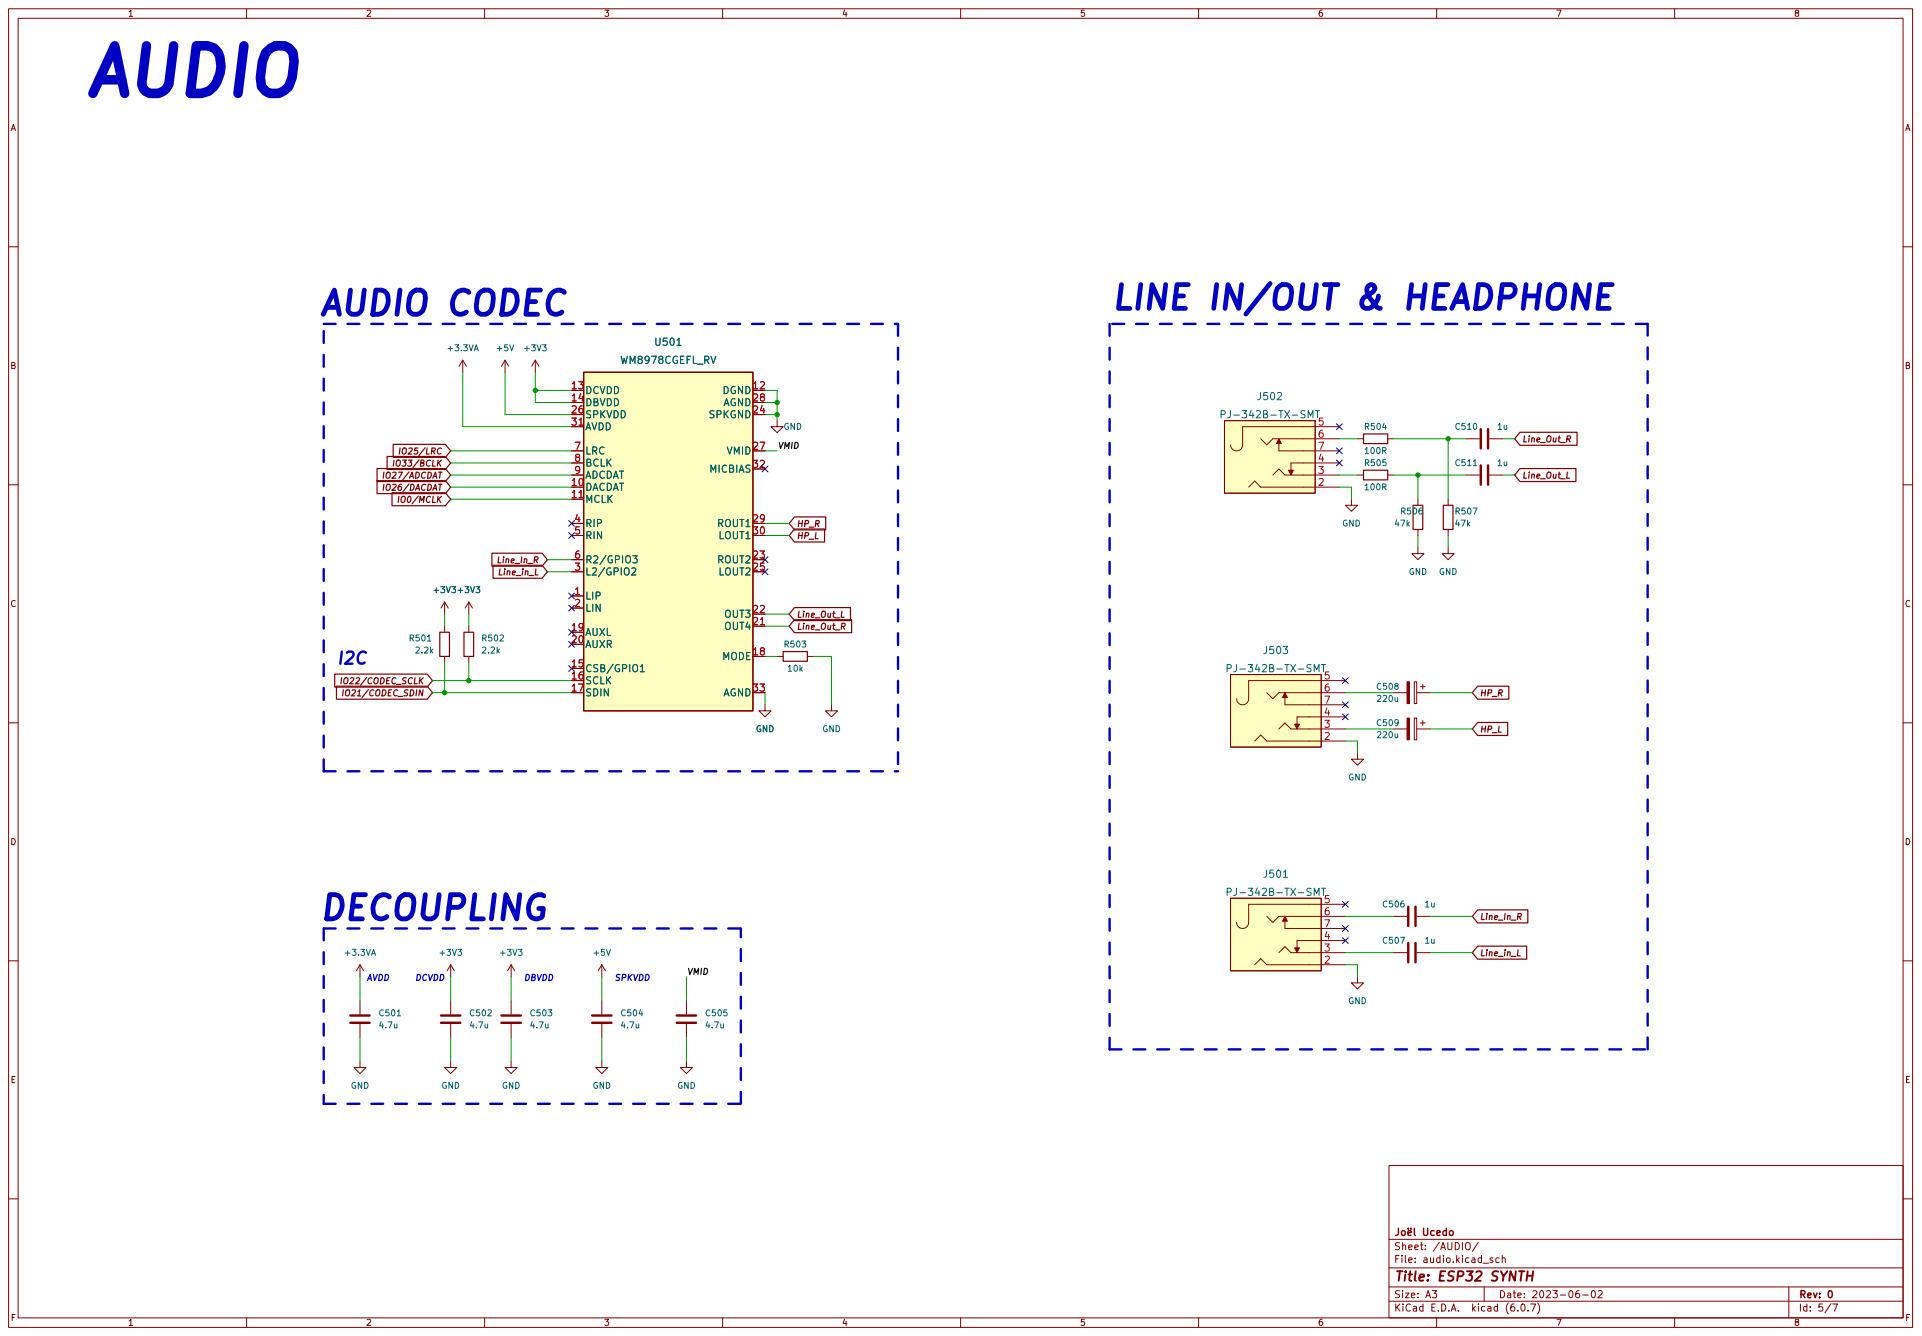
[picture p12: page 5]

File: audio.kicad_sch Sheet: /AUDIO/ þÿJoël Ucedo

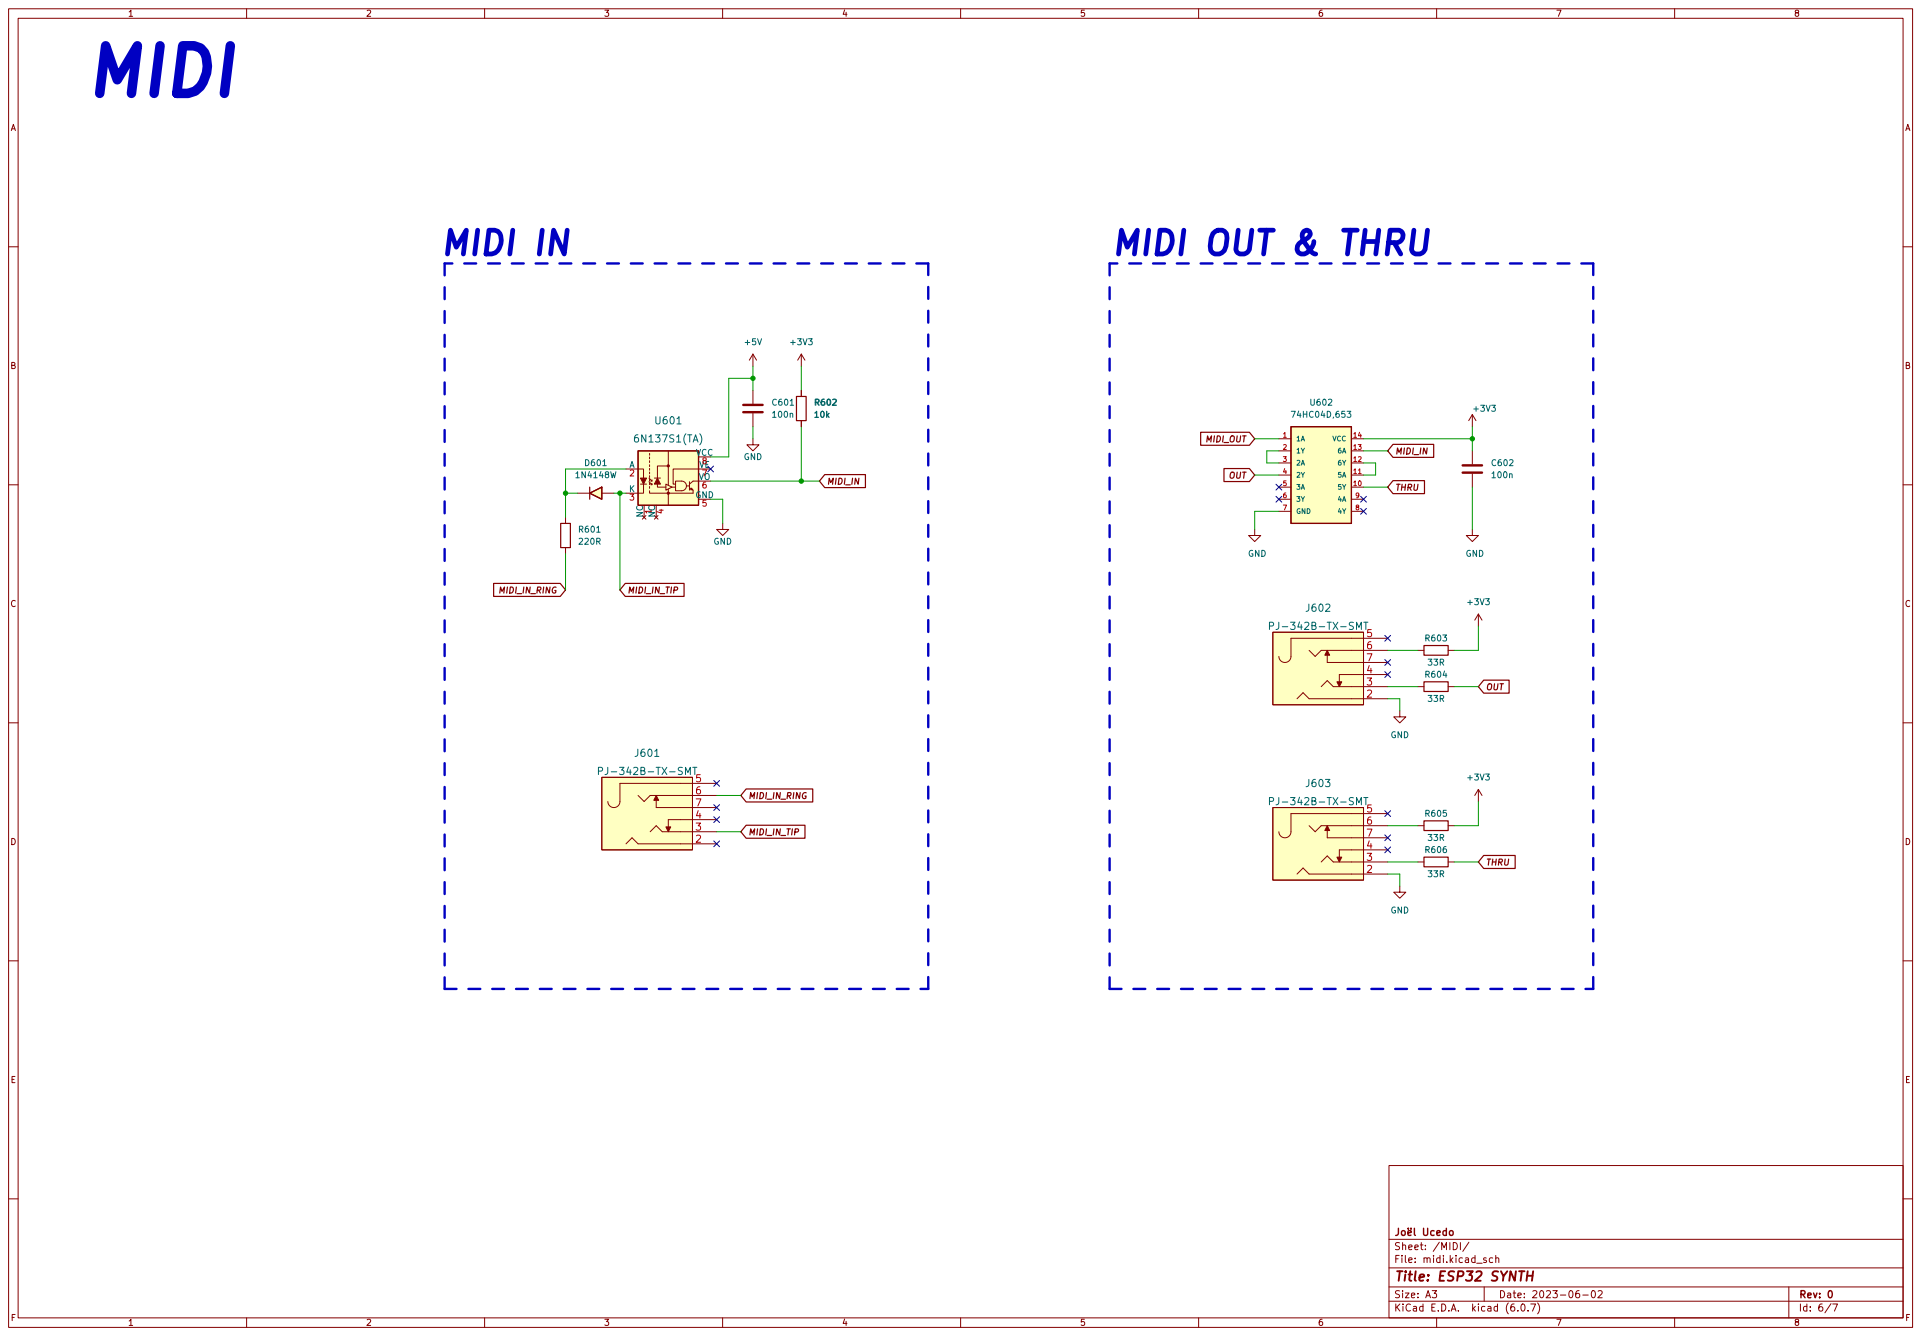
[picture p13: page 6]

File: midi.kicad_sch Sheet: /MIDI/ þÿJoël Ucedo NC1 A


HC 3V3 OK HCT 3V3 NOK

File: mux_pots.kicad_sch Sheet: /MUX - POTS/ þÿJoël Ucedo

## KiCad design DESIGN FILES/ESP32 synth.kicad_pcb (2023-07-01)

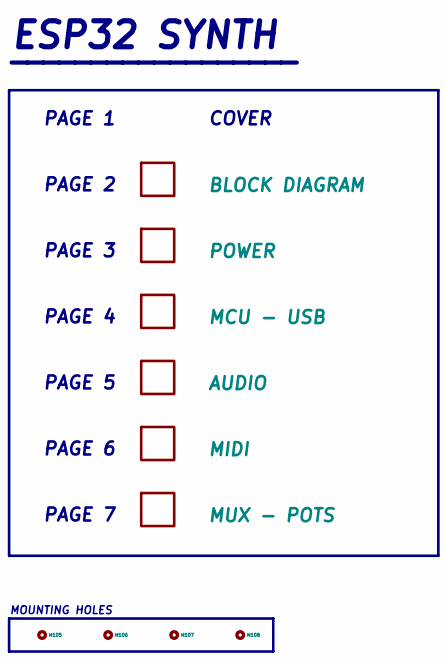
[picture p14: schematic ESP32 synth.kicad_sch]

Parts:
H105, H106, H107, H108: MountingHole; MountingHole_2.5mm

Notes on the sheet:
PAGE 4
COVER
PAGE 2
PAGE 5
ESP32 SYNTH
PAGE 6
MOUNTING HOLES
__________________
PAGE 7
PAGE 1
PAGE 3

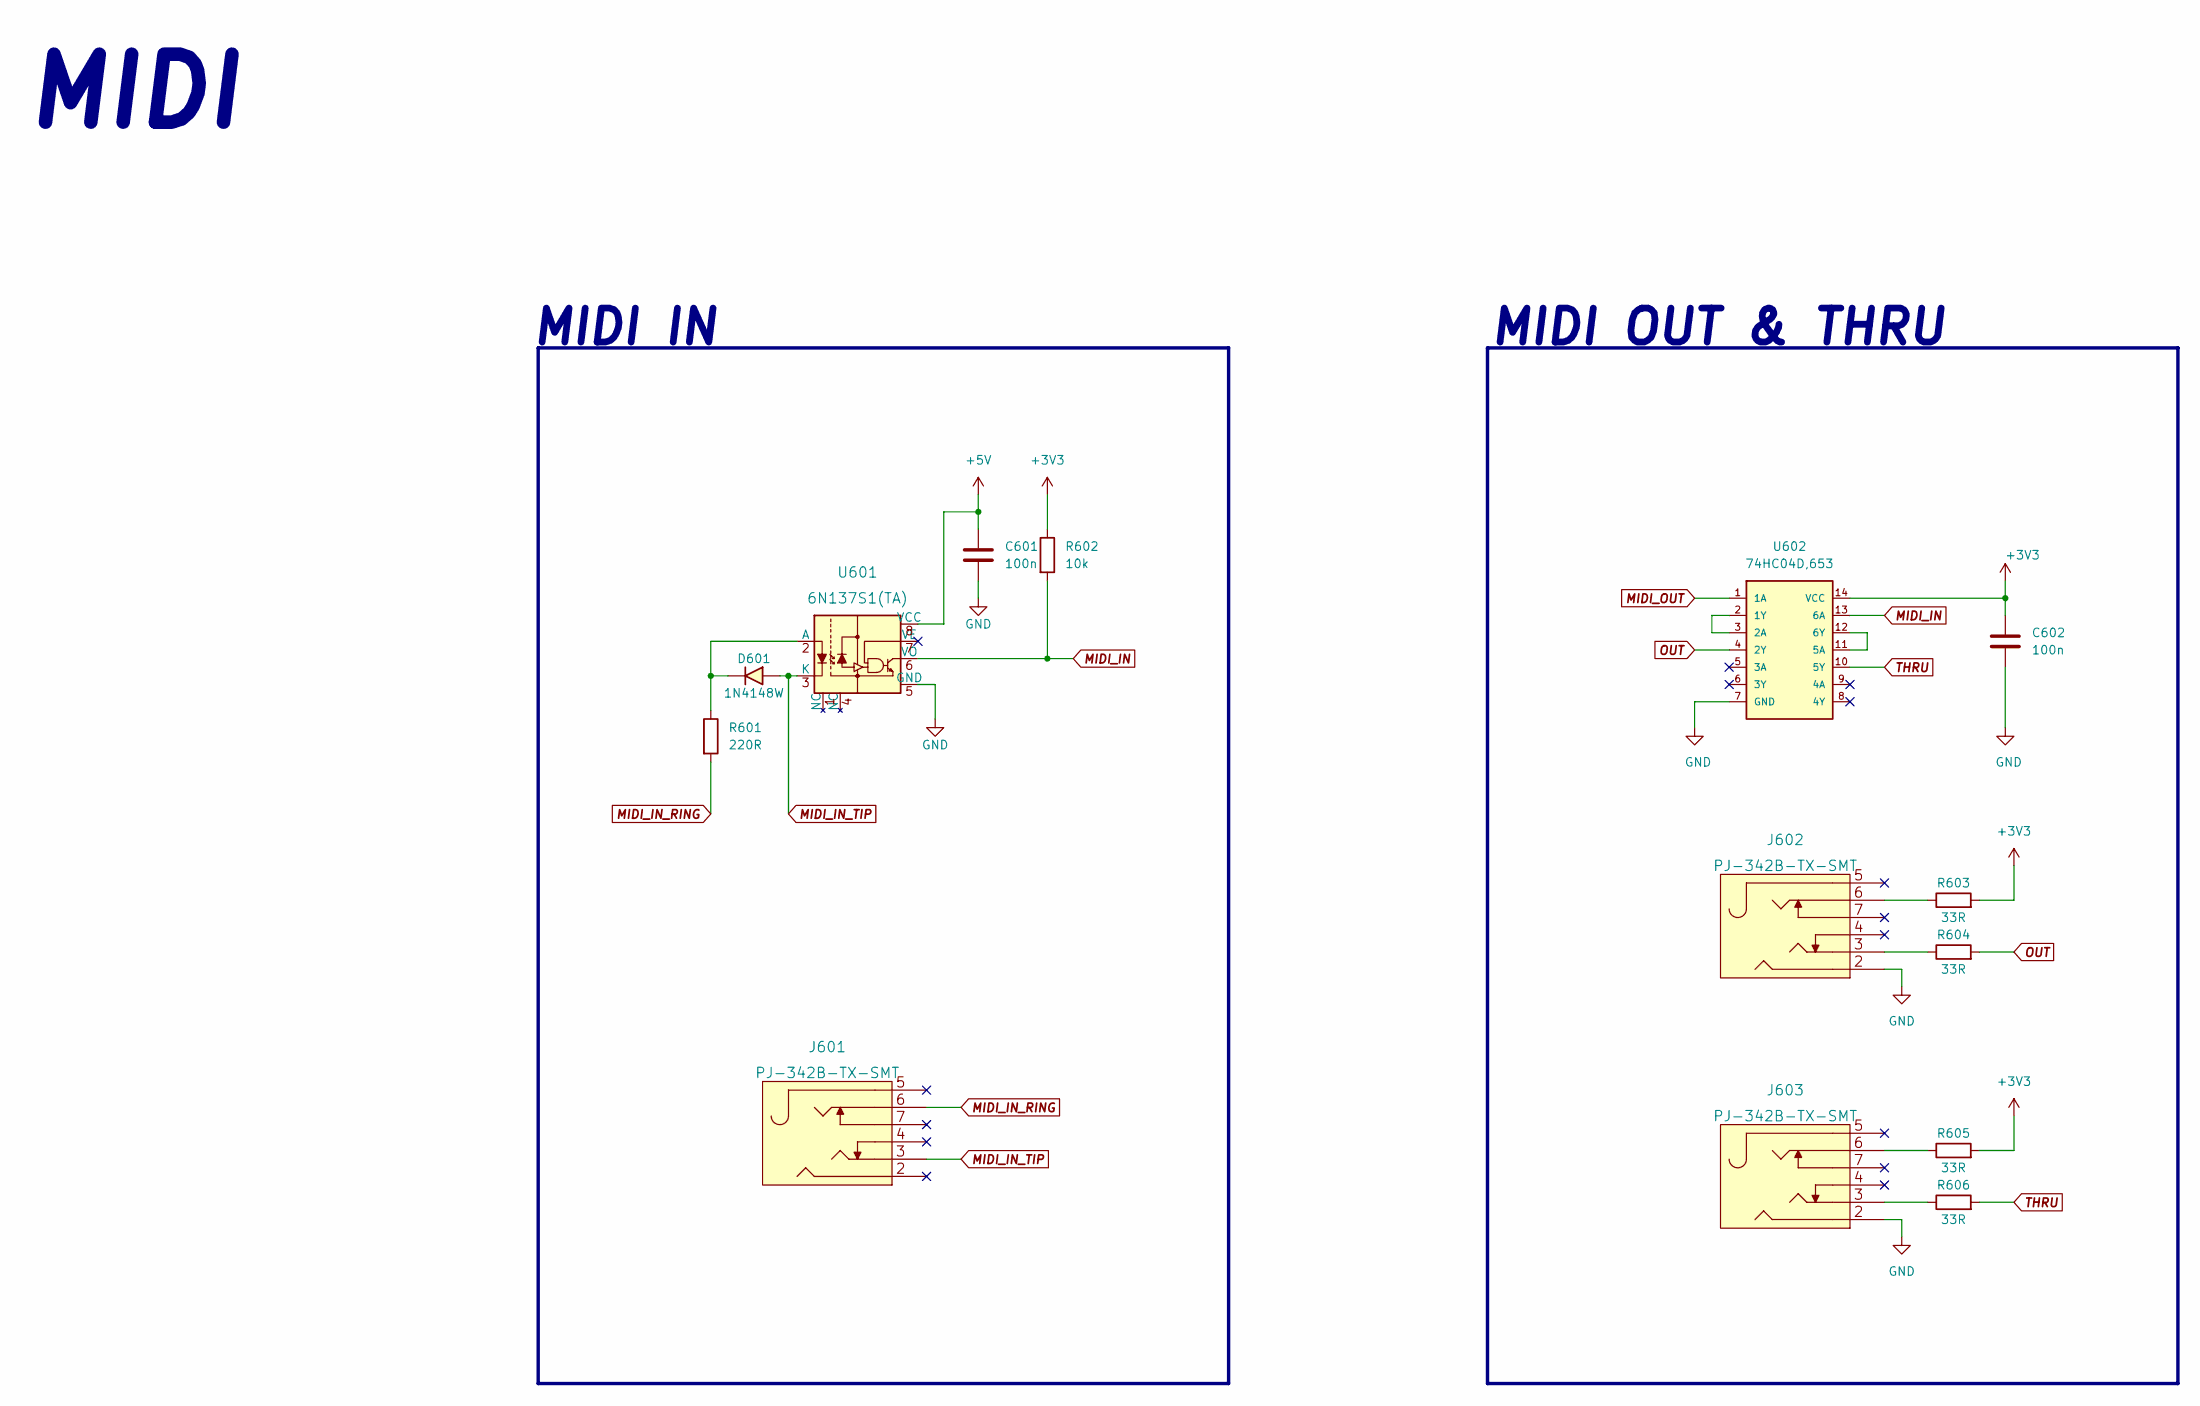
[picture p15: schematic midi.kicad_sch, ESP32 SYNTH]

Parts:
C601, C602: 100n; CC0603KRX7R9BB104_0603
D601: 1N4148W; 1N4148W_SOD-123
J601, J602, J603: PJ-342B-TX-SMT
R601: 220R; 0603WAF2200T5E
R602: 10k; 0603WAF1002T5E
R603, R604, R605, R606: 33R; 0603WAF330JT5E
U601: 6N137S1(TA); 6N137S1_TA_SMD-8P; MPN 6N137; Digi-Key_PN 160-1791-ND
U602: 74HC04D,653; 74HC04D_653_SOIC-14; MPN 74HC04D,653

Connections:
+3V3: C602.1, R602.1, R603.2, R605.2, U602.14 (VCC); also elsewhere on the board
+5V: C601.1, U601.8 (VCC); also elsewhere on the board
GND: C601.2, C602.2, J602.2, J603.2, U601.5 (GND), U602.7 (GND); also elsewhere on the board
MIDI_IN: R602.2, U601.6 (VO), U602.13 (6A); also elsewhere on the board
MIDI_IN_RING: J601.6, R601.2
MIDI_IN_TIP: D601.2 (A), J601.3, U601.3 (K)
MIDI_OUT: U602.1 (1A); also elsewhere on the board
unnamed: D601.1 (K), R601.1, U601.2 (A)
unnamed: J602.3, R604.1
unnamed: J602.6, R603.1
unnamed: J603.3, R606.1
unnamed: J603.6, R605.1
unnamed: U602.2 (1Y), U602.3 (2A)
unnamed: U602.11 (5A), U602.12 (6Y)
OUT: R604.2, U602.4 (2Y)
THRU: R606.2, U602.10 (5Y)

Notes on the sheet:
MIDI OUT & THRU
MIDI IN
MIDI

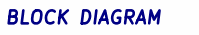
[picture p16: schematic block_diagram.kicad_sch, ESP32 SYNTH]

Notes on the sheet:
BLOCK DIAGRAM

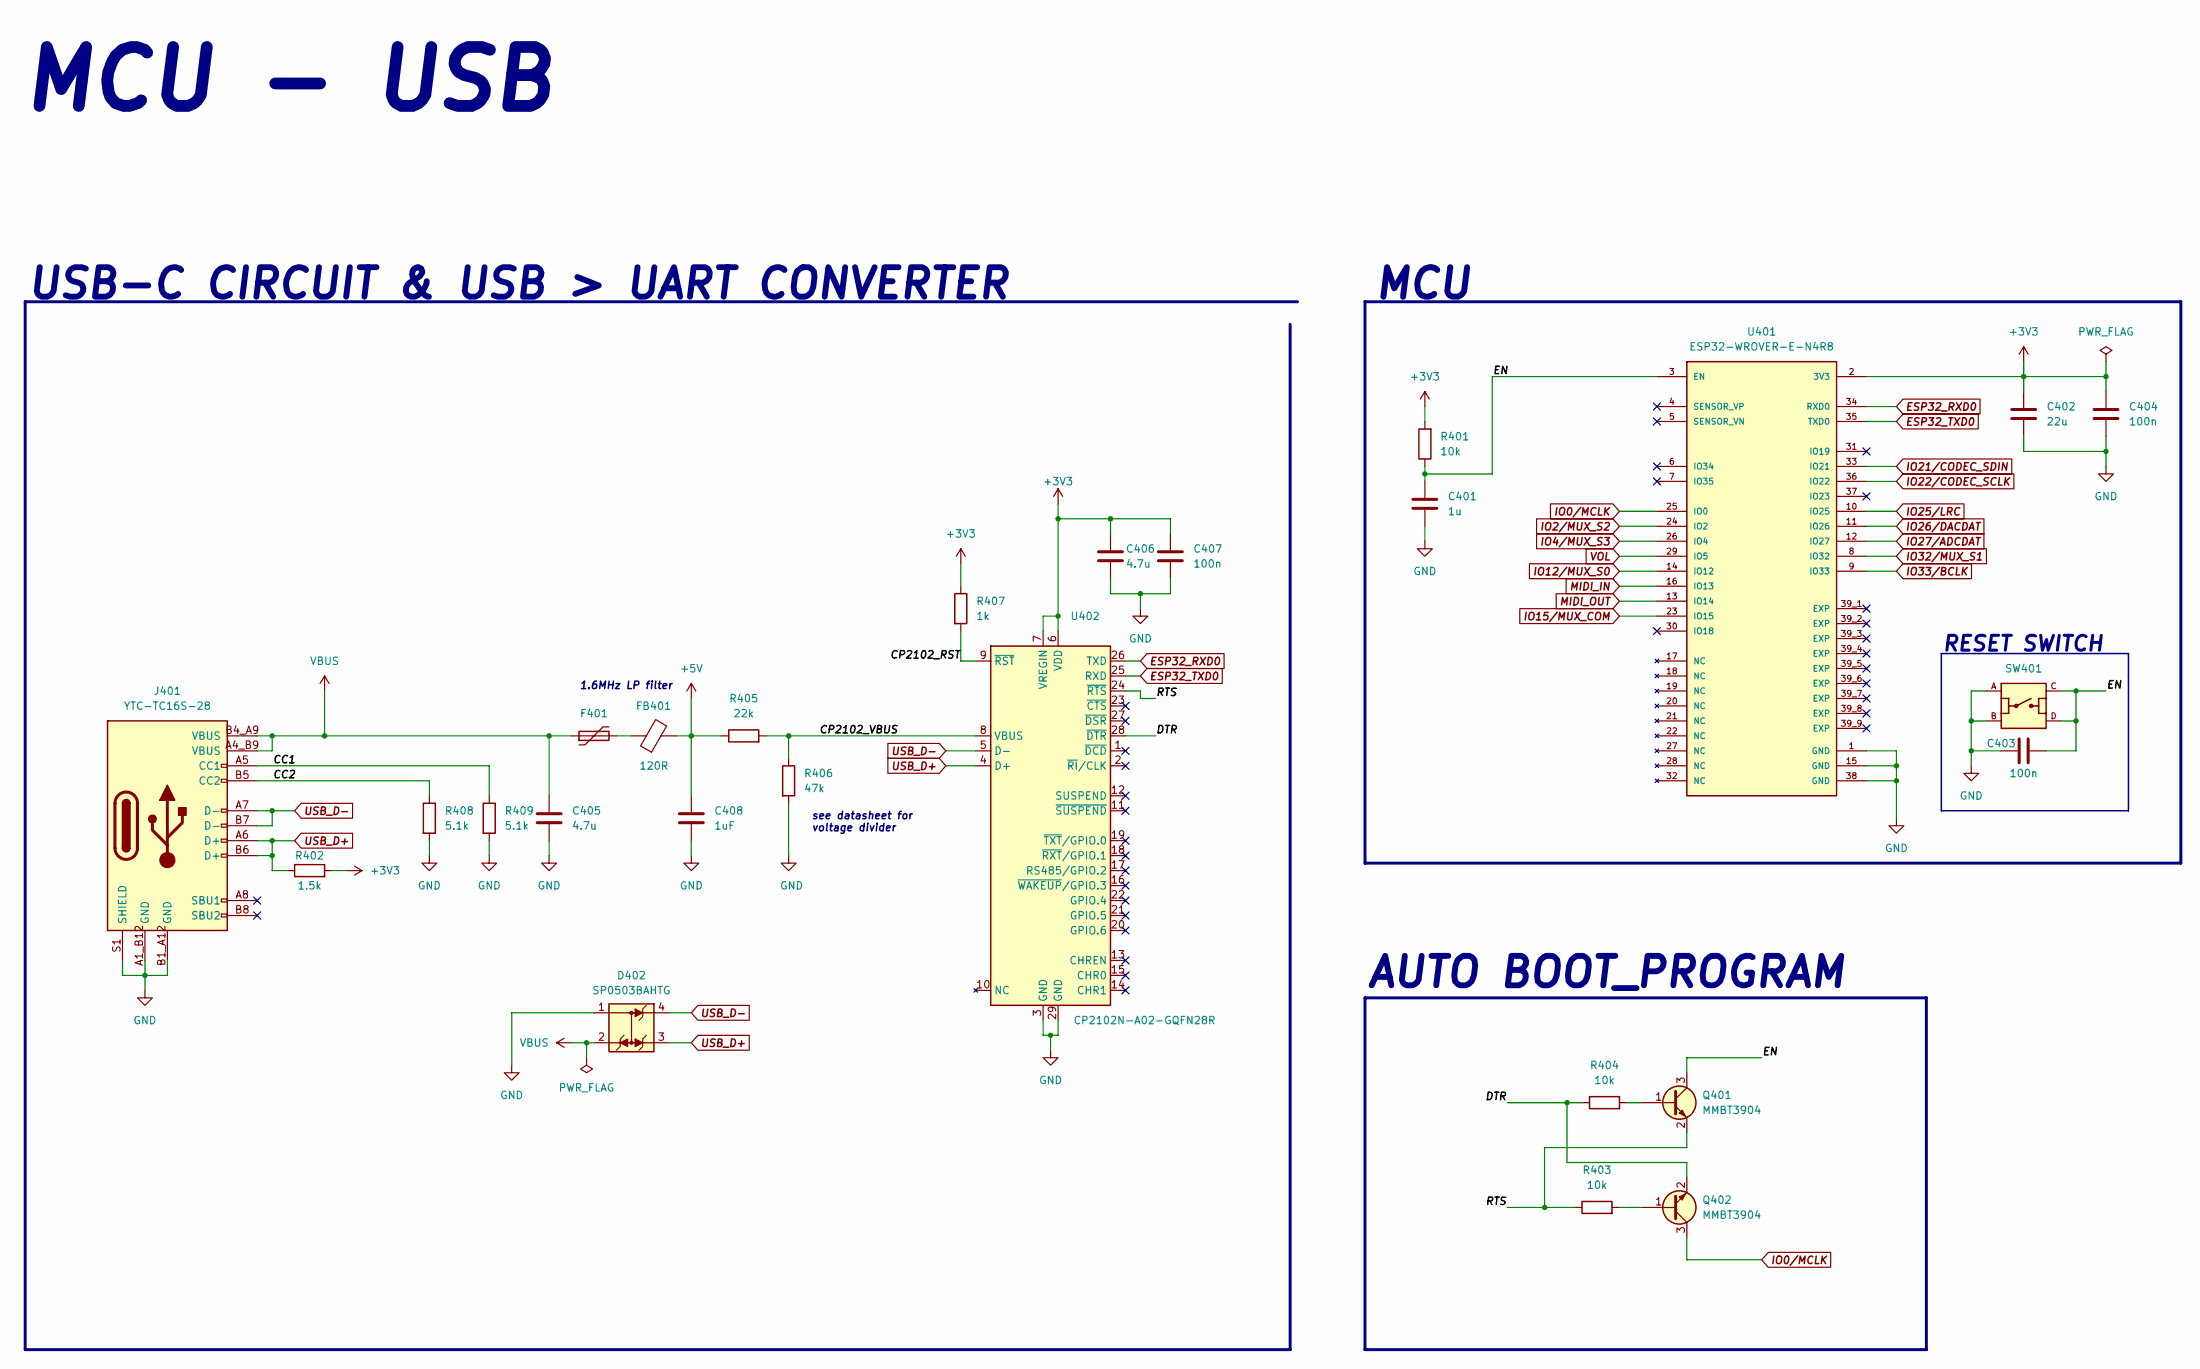
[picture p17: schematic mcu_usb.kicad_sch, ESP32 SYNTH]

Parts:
C401: 1u; CL10A105KB8NNNC_0603
C402: 22u; 0603_CL10A226MQ8NRNC
C403, C404, C407: 100n; CC0603KRX7R9BB104_0603
C405, C406: 4.7u; CL10A475KO8NNNC_0603
C408: 1uF; CL10A105KB8NNNC_0603
D402: SP0503BAHTG; SP0503BAHTG_SOT-143; MPN SP0503BAHTG; Digi-Key_PN F2715CT-ND
F401: SMD0805P020TF; 0805_SMD0805P020TF
FB401: 120R; 0603_BLM18AG121SN1D
J401: YTC-TC16S-28
Q401, Q402: MMBT3904; MMBT3904_SOT-23
R401, R403, R404: 10k; 0603WAF1002T5E
R402: 1.5k; CQ03WAJ0152T5E
R405: 22k; 0603WAF2202T5E
R406: 47k; 0603WAF4702T5E
R407: 1k; 0603WAF1001T5E
R408, R409: 5.1k; 0603WAF5101T5E
SW401: TS-1187A-B-A-B; TS-1187A-B-A-B_smd
U401: ESP32-WROVER-E-N4R8; XCVR_ESP32-WROVER-E-N4R8; PARTREV 1.6
U402: CP2102N-A02-GQFN28R; CP2102N-A02-GQFN28R_QFN-28

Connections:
+3V3: C402.1, C404.1, C406.1, C407.1, R401.2, R402.2, R407.1, U401.2 (3V3), U402.6 (VDD), U402.7 (VREGIN); also elsewhere on the board
+5V: C408.1, FB401.2, R405.1; also elsewhere on the board
/MCU - USB/CC1: J401.A5 (CC1), R409.1
/MCU - USB/CC2: J401.B5 (CC2), R408.1
/MCU - USB/CP2102_RST: R407.2, U402.9 (~RST)
/MCU - USB/CP2102_VBUS: R405.2, R406.1, U402.8 (VBUS)
/MCU - USB/DTR: Q402.2 (E), R404.1, U402.28 (~DTR)
/MCU - USB/EN: C401.1, C403.2, Q401.3 (C), R401.1, SW401.C, SW401.D, U401.3 (EN)
/MCU - USB/RTS: Q401.2 (E), R403.1, U402.24 (~RTS)
ESP32_RXD0: U401.34 (RXD0), U402.26 (TXD)
ESP32_TXD0: U401.35 (TXD0), U402.25 (RXD)
GND: C401.2, C402.2, C403.1, C404.2, C405.2, C406.2, C407.2, C408.2, D402.1, J401.A1_B12 (GND), J401.B1_A12 (GND), J401.S1 (SHIELD), R406.2, R408.2, R409.2, SW401.A, SW401.B, U401.1 (GND), U401.15 (GND), U401.38 (GND), U402.3 (GND), U402.29 (GND); also elsewhere on the board
IO0/MCLK: Q402.3 (C), U401.25 (IO0); also elsewhere on the board
IO2/MUX_S2: U401.24 (IO2); also elsewhere on the board
IO4/MUX_S3: U401.26 (IO4); also elsewhere on the board
IO12/MUX_S0: U401.14 (IO12); also elsewhere on the board
IO15/MUX_COM: U401.23 (IO15); also elsewhere on the board
IO21/CODEC_SDIN: U401.33 (IO21); also elsewhere on the board
IO22/CODEC_SCLK: U401.36 (IO22); also elsewhere on the board
IO25/LRC: U401.10 (IO25); also elsewhere on the board
IO26/DACDAT: U401.11 (IO26); also elsewhere on the board
IO27/ADCDAT: U401.12 (IO27); also elsewhere on the board
IO32/MUX_S1: U401.8 (IO32); also elsewhere on the board
IO33/BCLK: U401.9 (IO33); also elsewhere on the board
MIDI_IN: U401.16 (IO13); also elsewhere on the board
MIDI_OUT: U401.13 (IO14); also elsewhere on the board
unnamed: F401.2, FB401.1
unnamed: Q401.1 (B), R404.2
unnamed: Q402.1 (B), R403.2
USB_D+: D402.3, J401.A6 (D+), J401.B6 (D+), R402.1, U402.4 (D+)
USB_D-: D402.4, J401.A7 (D-), J401.B7 (D-), U402.5 (D-)
VBUS: C405.1, D402.2, F401.1, J401.A4_B9 (VBUS), J401.B4_A9 (VBUS)
VOL: U401.29 (IO5); also elsewhere on the board

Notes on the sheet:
USB-C CIRCUIT & USB > UART CONVERTER
see datasheet for voltage divider
RESET SWITCH
MCU
1.6MHz LP filter
AUTO BOOT_PROGRAM
MCU - USB

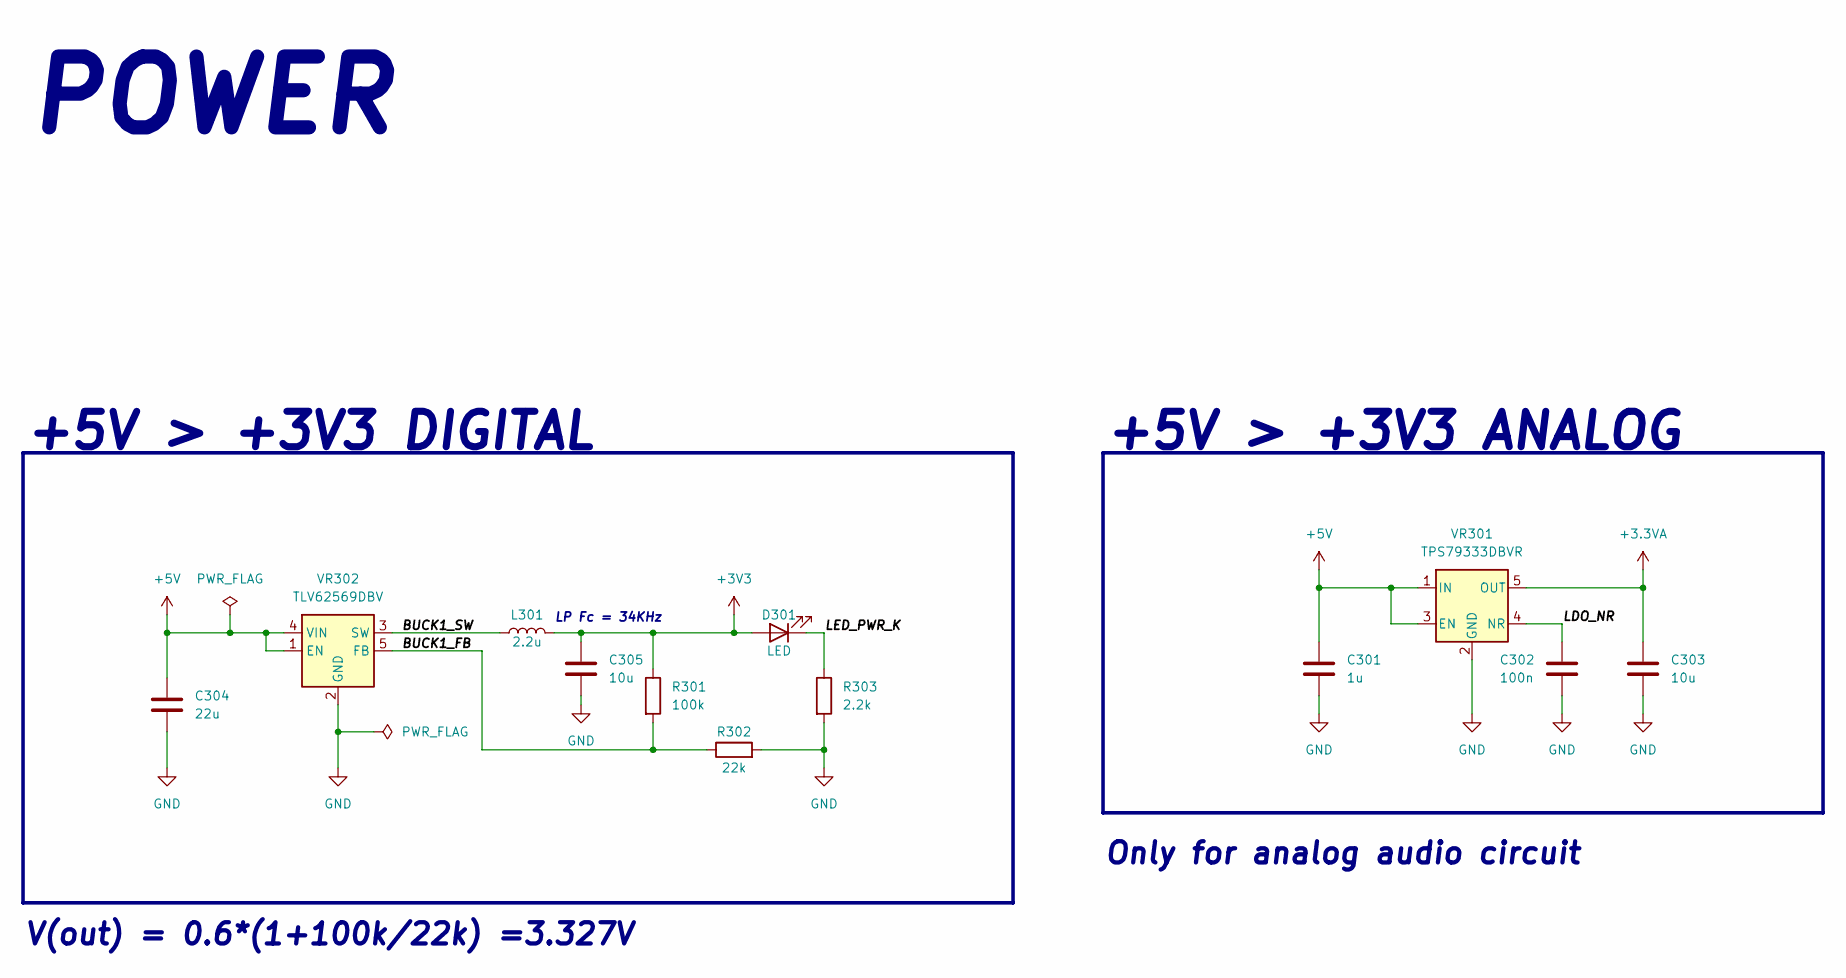
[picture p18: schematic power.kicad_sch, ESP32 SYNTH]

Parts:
C301: 1u; CL10A105KB8NNNC_0603
C302: 100n; CC0603KRX7R9BB104_0603
C303: 10u; 0603_CL10A106KP8NNNC
C304: 22u; 0603_CL10A226MQ8NRNC
C305: 10u; CL10A106MA8NRNC_0603
D301: LED; LED_D3.0mm
L301: 2.2u; CD32YP0302-2R2M
R301: 100k; 0603WAF1003T5E
R302: 22k; 0603WAF2200T5E
R303: 2.2k; 0603WAF2201T5E
VR301: TPS79333DBVR; TPS79333DBVR_SOT-23-5
VR302: TLV62569DBV; TLV62569DBVR

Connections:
+3.3VA: C303.1, VR301.5 (OUT); also elsewhere on the board
+3V3: C305.1, D301.2 (A), L301.2, R301.1; also elsewhere on the board
+5V: C301.1, C304.1, VR301.1 (IN), VR301.3 (EN), VR302.1 (EN), VR302.4 (VIN); also elsewhere on the board
/POWER/BUCK1_FB: R301.2, R302.1, VR302.5 (FB)
/POWER/BUCK1_SW: L301.1, VR302.3 (SW)
/POWER/LDO_NR: C302.1, VR301.4 (NR)
/POWER/LED_PWR_K: D301.1 (K), R303.1
GND: C301.2, C302.2, C303.2, C304.2, C305.2, R302.2, R303.2, VR301.2 (GND), VR302.2 (GND); also elsewhere on the board

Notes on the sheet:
POWER
LP Fc = 34KHz
+5V > +3V3 DIGITAL
+5V > +3V3 ANALOG
Only for analog audio circuit
V(out) = 0.6*(1+100k/22k) =3.327V

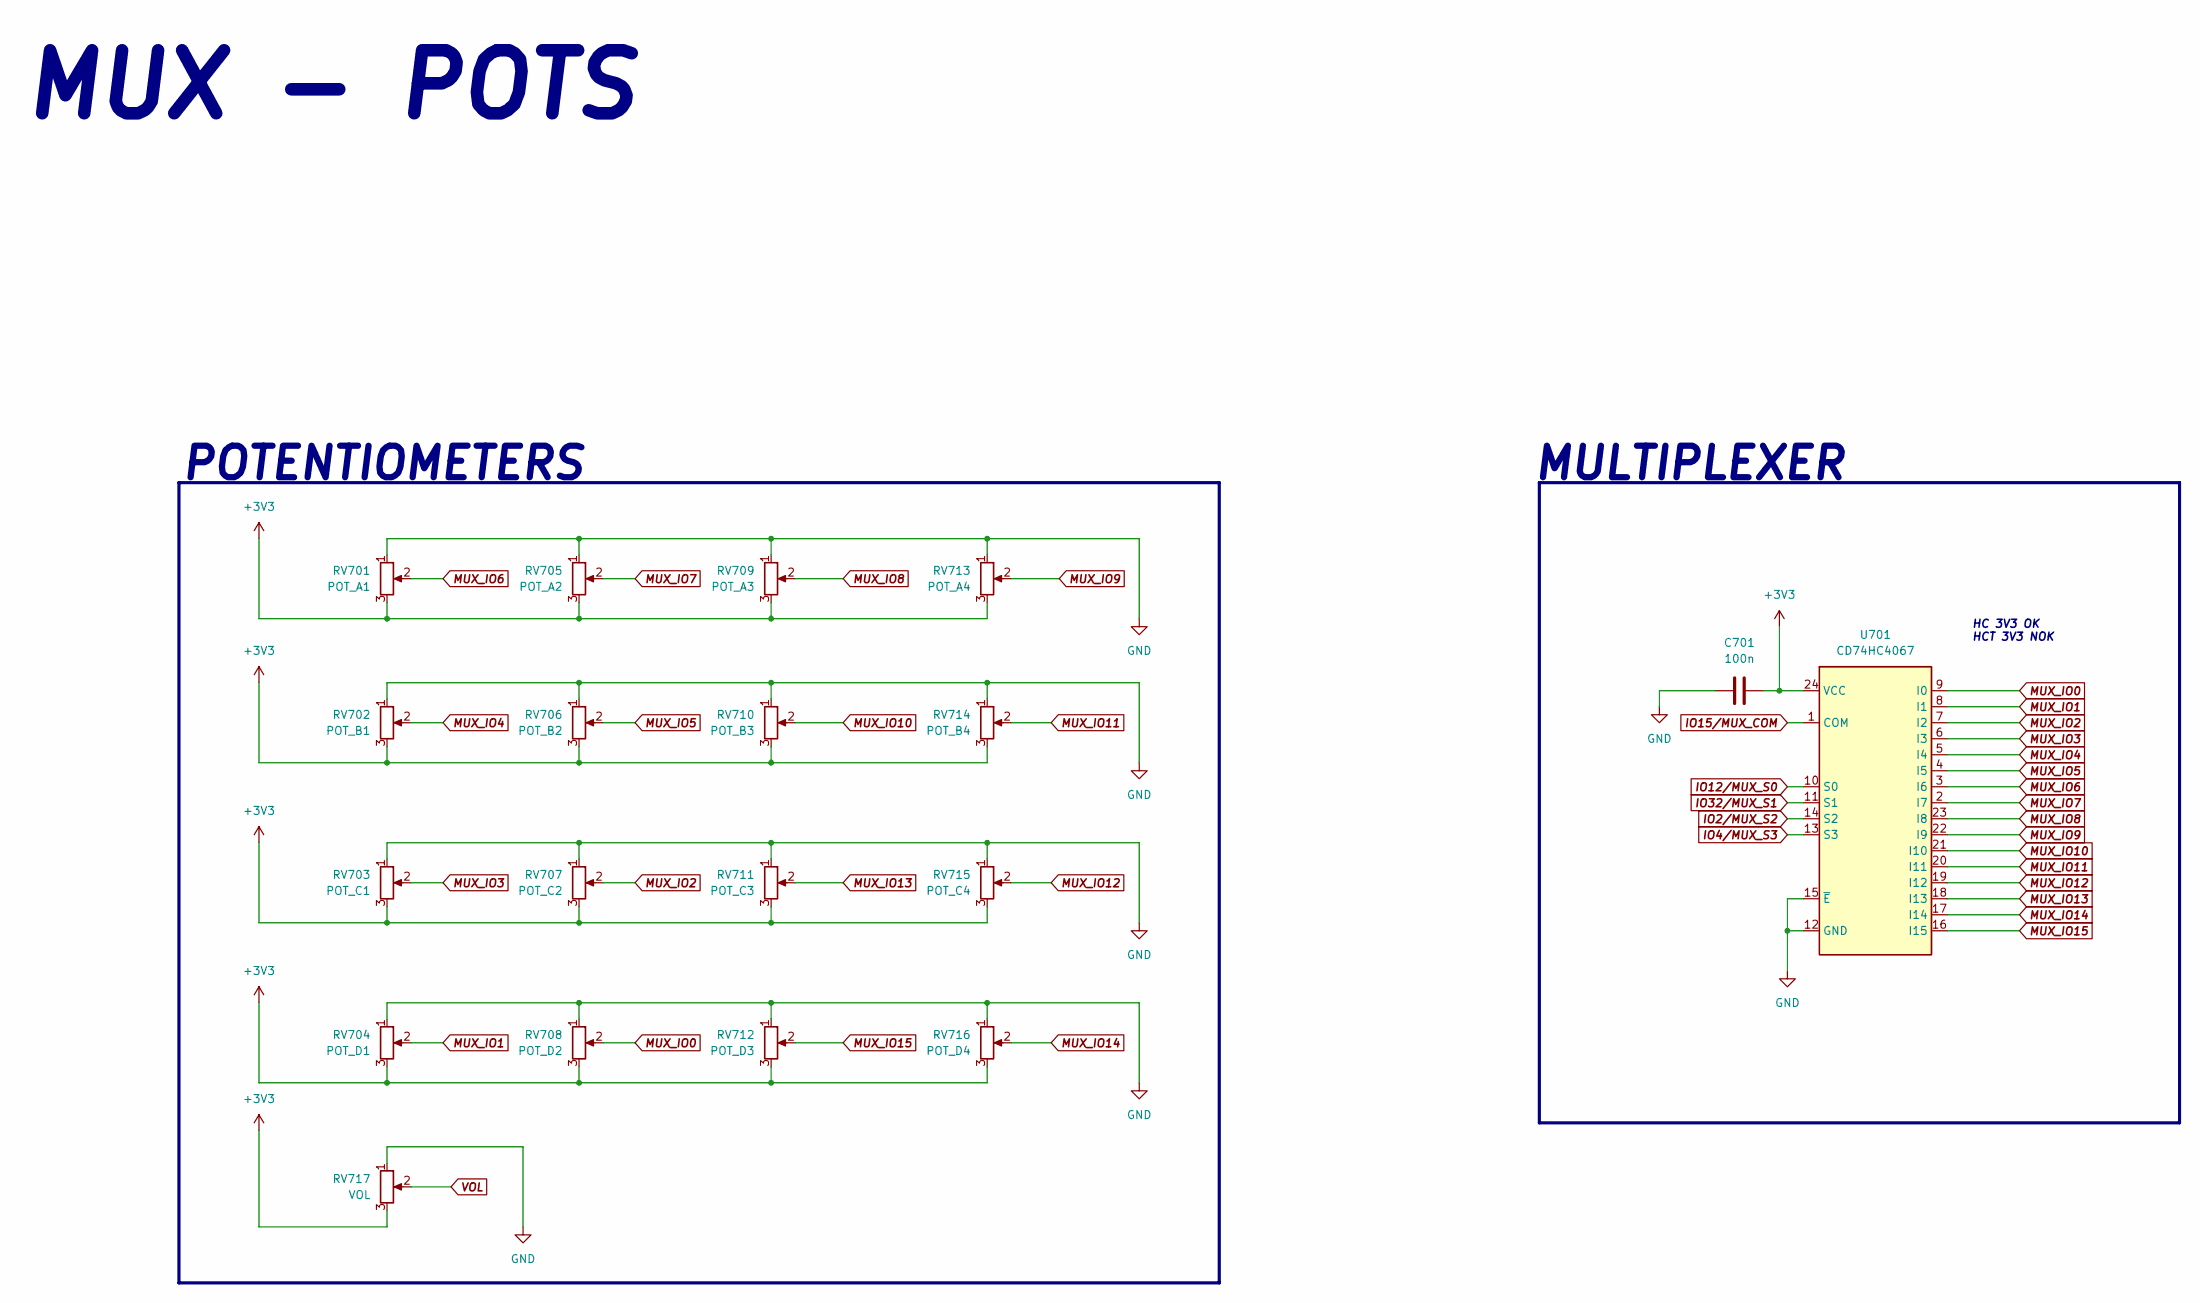
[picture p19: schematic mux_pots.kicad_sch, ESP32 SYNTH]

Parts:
C701: 100n; CC0603KRX7R9BB104_0603
RV701: POT_A1; RK09D1130C2P
RV702: POT_B1; RK09D1130C2P
RV703: POT_C1; RK09D1130C2P
RV704: POT_D1; RK09D1130C2P
RV705: POT_A2; RK09D1130C2P
RV706: POT_B2; RK09D1130C2P
RV707: POT_C2; RK09D1130C2P
RV708: POT_D2; RK09D1130C2P
RV709: POT_A3; RK09D1130C2P
RV710: POT_B3; RK09D1130C2P
RV711: POT_C3; RK09D1130C2P
RV712: POT_D3; RK09D1130C2P
RV713: POT_A4; RK09D1130C2P
RV714: POT_B4; RK09D1130C2P
RV715: POT_C4; RK09D1130C2P
RV716: POT_D4; RK09D1130C2P
RV717: VOL; RK09D1130C2P
U701: CD74HC4067; CD74HC4067_SOIC-24

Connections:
+3V3: C701.2, RV701.3, RV702.3, RV703.3, RV704.3, RV705.3, RV706.3, RV707.3, RV708.3, RV709.3, RV710.3, RV711.3, RV712.3, RV713.3, RV714.3, RV715.3, RV716.3, RV717.3, U701.24 (VCC); also elsewhere on the board
GND: C701.1, RV701.1, RV702.1, RV703.1, RV704.1, RV705.1, RV706.1, RV707.1, RV708.1, RV709.1, RV710.1, RV711.1, RV712.1, RV713.1, RV714.1, RV715.1, RV716.1, RV717.1, U701.12 (GND), U701.15 (~E); also elsewhere on the board
IO2/MUX_S2: U701.14 (S2); also elsewhere on the board
IO4/MUX_S3: U701.13 (S3); also elsewhere on the board
IO12/MUX_S0: U701.10 (S0); also elsewhere on the board
IO15/MUX_COM: U701.1 (COM); also elsewhere on the board
IO32/MUX_S1: U701.11 (S1); also elsewhere on the board
MUX_IO0: RV708.2, U701.9 (I0)
MUX_IO1: RV704.2, U701.8 (I1)
MUX_IO2: RV707.2, U701.7 (I2)
MUX_IO3: RV703.2, U701.6 (I3)
MUX_IO4: RV702.2, U701.5 (I4)
MUX_IO5: RV706.2, U701.4 (I5)
MUX_IO6: RV701.2, U701.3 (I6)
MUX_IO7: RV705.2, U701.2 (I7)
MUX_IO8: RV709.2, U701.23 (I8)
MUX_IO9: RV713.2, U701.22 (I9)
MUX_IO10: RV710.2, U701.21 (I10)
MUX_IO11: RV714.2, U701.20 (I11)
MUX_IO12: RV715.2, U701.19 (I12)
MUX_IO13: RV711.2, U701.18 (I13)
MUX_IO14: RV716.2, U701.17 (I14)
MUX_IO15: RV712.2, U701.16 (I15)
VOL: RV717.2; also elsewhere on the board

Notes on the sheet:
MULTIPLEXER
POTENTIOMETERS
MUX - POTS
HC 3V3 OK HCT 3V3 NOK

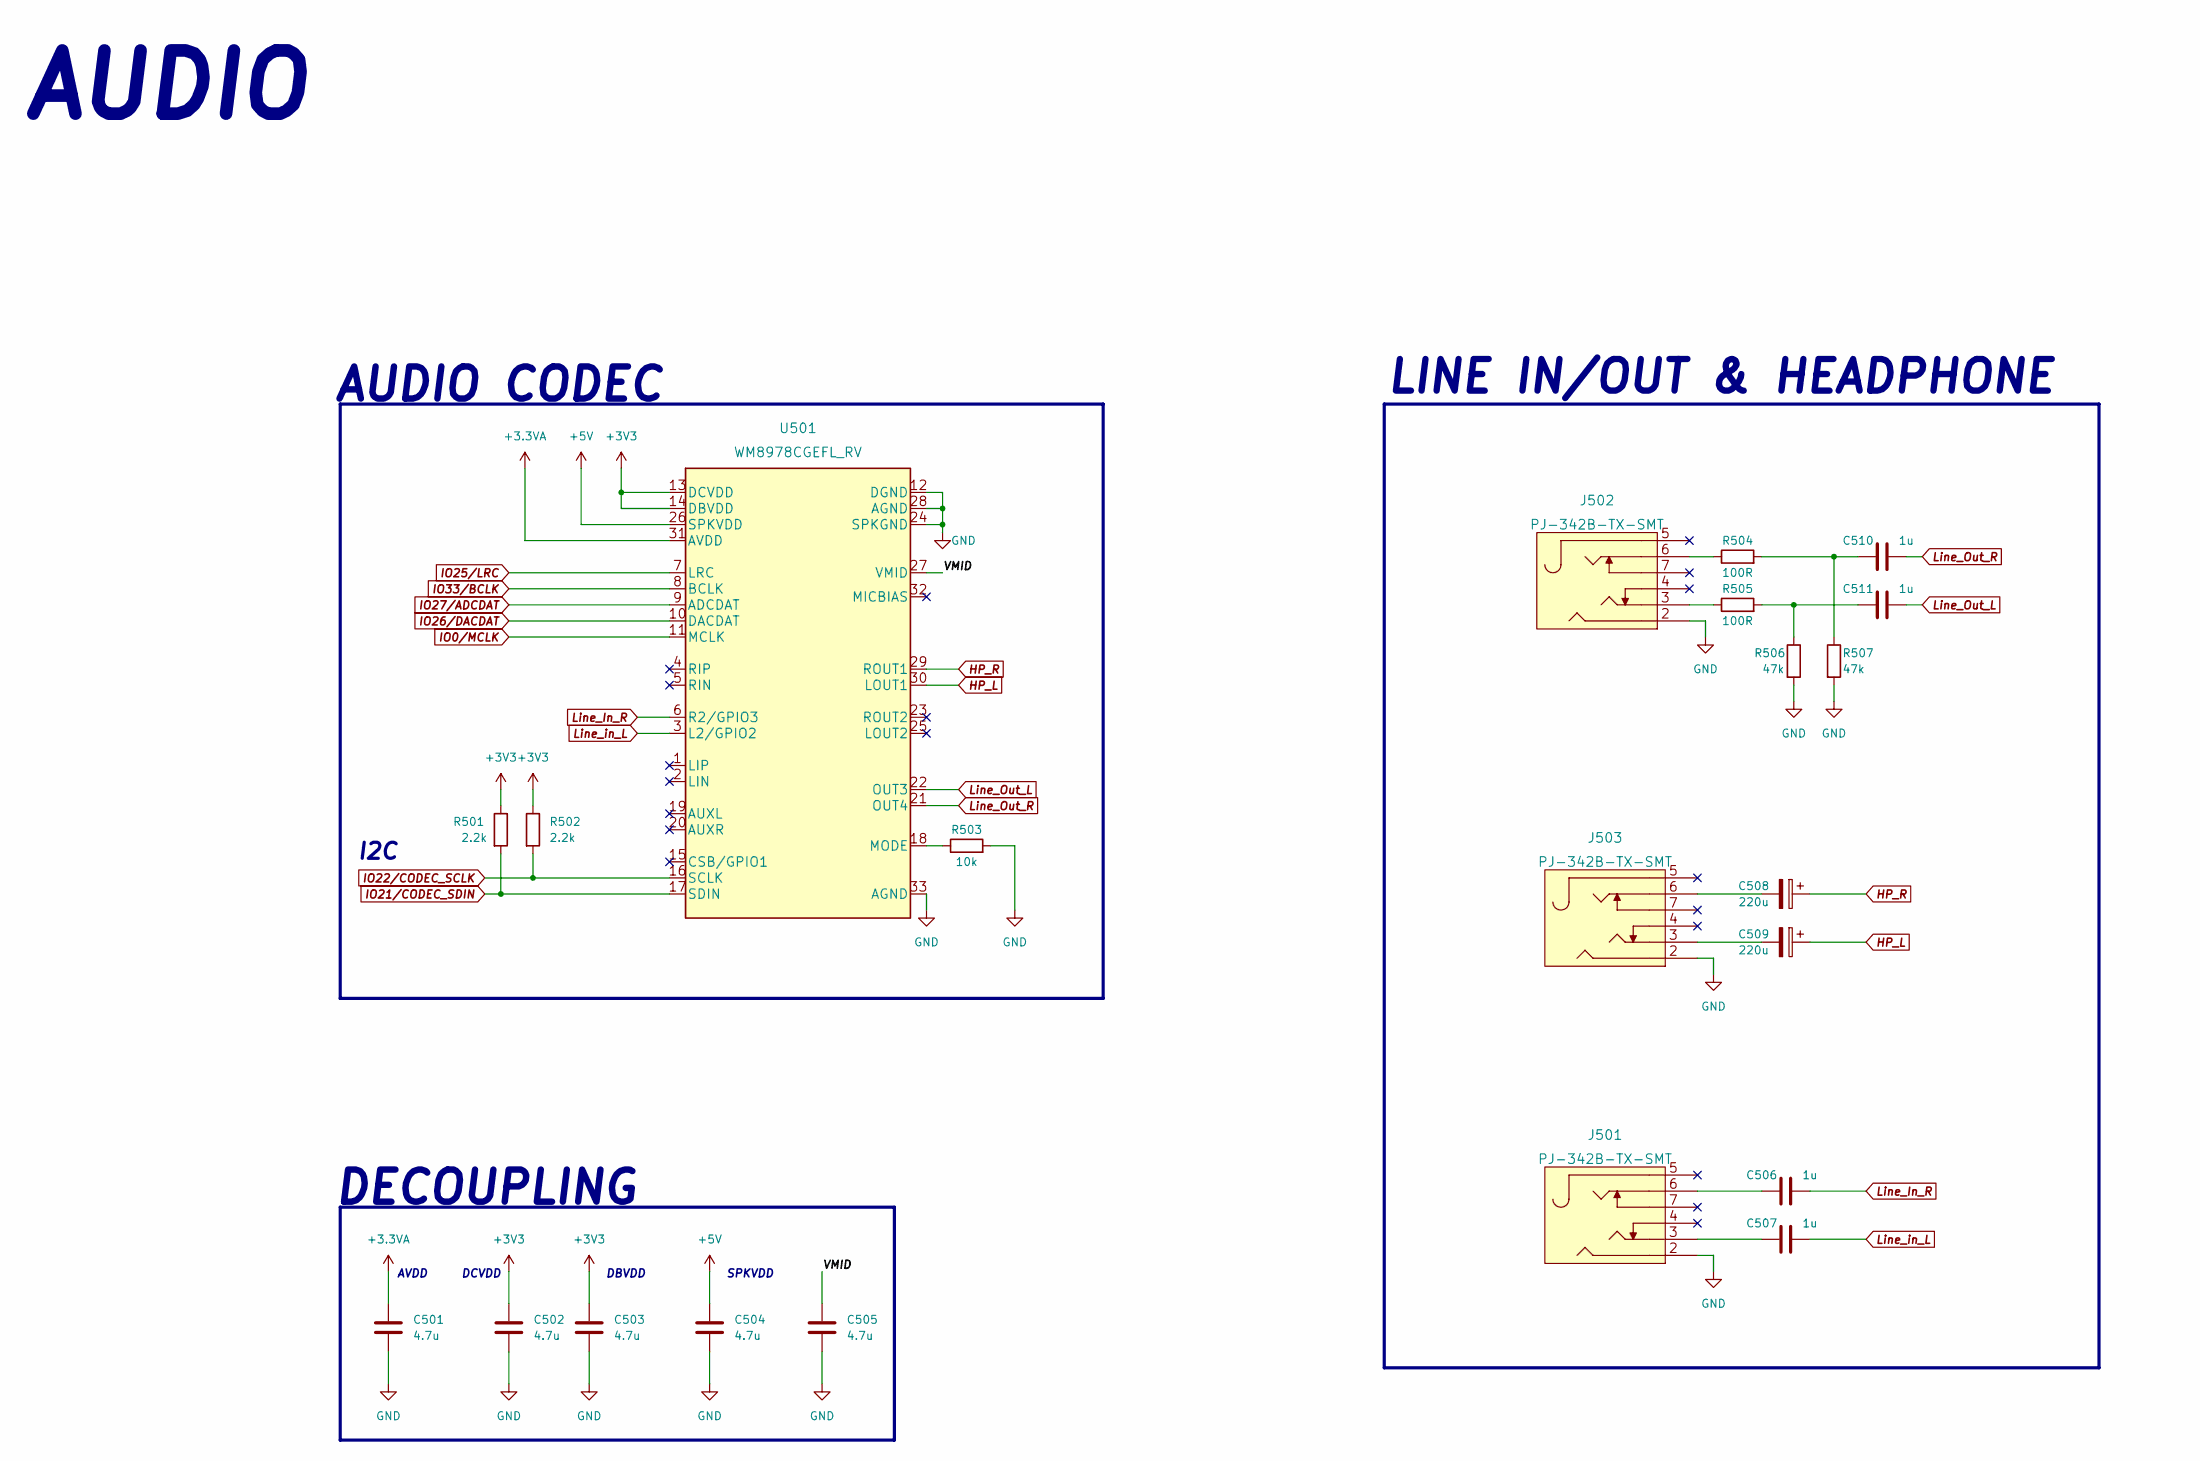
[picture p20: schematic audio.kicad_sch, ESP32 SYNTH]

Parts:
C501, C502, C503, C504, C505: 4.7u; CL10A475KO8NNNC_0603
C506, C507, C510, C511: 1u; CL10A105KB8NNNC_0603
C508, C509: 220u; RVT1A221M0605
J501, J502, J503: PJ-342B-TX-SMT
R501, R502: 2.2k; 0603WAF2201T5E
R503: 10k; 0603WAF1002T5E
R504, R505: 100R; 0603WAF1000T5E
R506, R507: 47k; 0603WAF4702T5E
U501: WM8978CGEFL_RV; WM8978CGEFL_RV_WQFN-32

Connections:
+3.3VA: C501.1, U501.31 (AVDD); also elsewhere on the board
+3V3: C502.1, C503.1, R501.1, R502.1, U501.13 (DCVDD), U501.14 (DBVDD); also elsewhere on the board
+5V: C504.1, U501.26 (SPKVDD); also elsewhere on the board
/AUDIO/VMID: C505.1, U501.27 (VMID)
GND: C501.2, C502.2, C503.2, C504.2, C505.2, J501.2, J502.2, J503.2, R503.2, R506.2, R507.2, U501.12 (DGND), U501.24 (SPKGND), U501.28 (AGND), U501.33 (AGND); also elsewhere on the board
HP_L: C509.1, U501.30 (LOUT1)
HP_R: C508.1, U501.29 (ROUT1)
IO0/MCLK: U501.11 (MCLK); also elsewhere on the board
IO21/CODEC_SDIN: R501.2, U501.17 (SDIN); also elsewhere on the board
IO22/CODEC_SCLK: R502.2, U501.16 (SCLK); also elsewhere on the board
IO25/LRC: U501.7 (LRC); also elsewhere on the board
IO26/DACDAT: U501.10 (DACDAT); also elsewhere on the board
IO27/ADCDAT: U501.9 (ADCDAT); also elsewhere on the board
IO33/BCLK: U501.8 (BCLK); also elsewhere on the board
Line_In_R: C506.2, U501.6 (R2/GPIO3)
Line_Out_L: C511.2, U501.22 (OUT3)
Line_Out_R: C510.2, U501.21 (OUT4)
Line_in_L: C507.2, U501.3 (L2/GPIO2)
unnamed: C506.1, J501.6
unnamed: C507.1, J501.3
unnamed: C508.2, J503.6
unnamed: C509.2, J503.3
unnamed: C510.1, R504.2, R507.1
unnamed: C511.1, R505.2, R506.1
unnamed: J502.3, R505.1
unnamed: J502.6, R504.1
unnamed: R503.1, U501.18 (MODE)

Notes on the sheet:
AUDIO CODEC
AUDIO
AVDD
DBVDD
DECOUPLING
I2C
SPKVDD
DCVDD
LINE IN/OUT & HEADPHONE

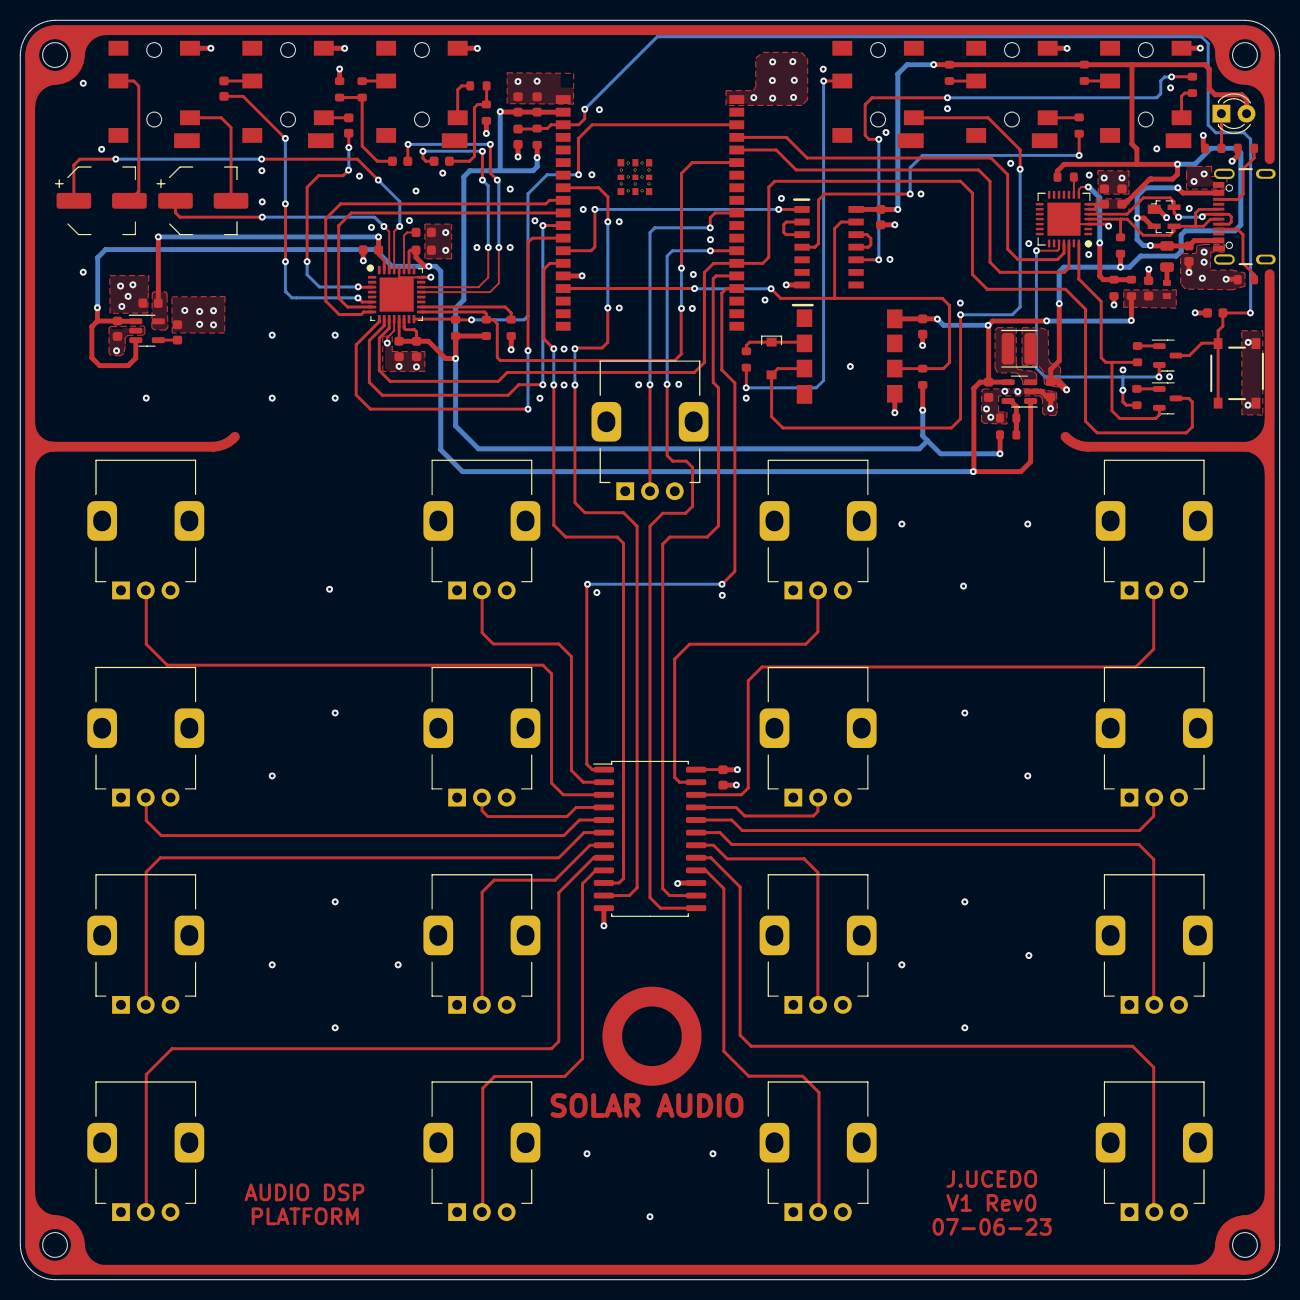
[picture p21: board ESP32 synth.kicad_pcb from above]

Board: 4 copper layers, 127.0 x 127.0 mm, 97 parts (0 on the bottom side), 81 nets.

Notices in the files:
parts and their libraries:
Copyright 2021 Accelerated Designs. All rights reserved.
